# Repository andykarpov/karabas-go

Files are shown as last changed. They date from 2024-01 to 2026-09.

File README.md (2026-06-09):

# Karabas-Go

A Spartan-6 based devboard to emulate different retro-computers.



The hardware design and documentation are licensed under [Creative Commons Attribution-NonCommercial-ShareAlike 4.0 International](http://creativecommons.org/licenses/by-nc-sa/4.0/).

FPGA cores, the firmware and other software parts are licensed by their own licenses.

### What's on the board:

- A 25k LE's Spartan-6 FPGA
- RP2040 MCU
- 4x USB Ports
- 2x 2MB 10ns SRAM chips
- 32MB SDRAM chip
- VGA 8:8:8 output
- On-board FT812 video processor
- 16-bit audio DAC
- SAM2695 midi synth
- 2x Sega/Atari compatible DB9 joystick ports
- CF card
- 2x microSD cards
- Tape In/Out interface
- FDD port
- Buzzer
- DS3221 RTC
- 1kB EEPROM
- ESP8266 Wi-Fi module

### PCB 

The latest PCB revision number is Rev.B4.
PCB Changelog: https://github.com/andykarpov/karabas-go/blob/master/PCB_CHANGELOG.md

Warning: Rev.B4 could be a bit incompatible with the 3D enclosure models due to microSD cards shifted a bit forward.

### FPGA Core Sources

- Boot Menu Core: https://github.com/andykarpov/karabas-go-core-menu
- Test Core: https://github.com/andykarpov/karabas-go-core-test
- TS-Conf Core: https://github.com/andykarpov/karabas-go-core-tsconf
- ZX Spectrum Next Core: https://github.com/andykarpov/karabas-go-core-next
- Karabas Pro Core: https://github.com/andykarpov/karabas-go-core-profi
- PCXT Core: https://github.com/andykarpov/karabas-go-core-pcxt
- NES Core: https://github.com/andykarpov/karabas-go-core-nes
- Radio RK86 Core: https://github.com/andykarpov/karabas-go-core-rk86
- Alf Core: https://github.com/andykarpov/karabas-go-core-alf
- PDP-11/70: https://github.com/tsybulin/karabas-go-core-pdp2026

### The Firmware Sources

- https://github.com/andykarpov/karabas-go-firmware

### Dev Tools

- https://github.com/andykarpov/karabas-go-tools

### PCB

- https://github.com/andykarpov/karabas-go-pcb

### Pre-production renders:

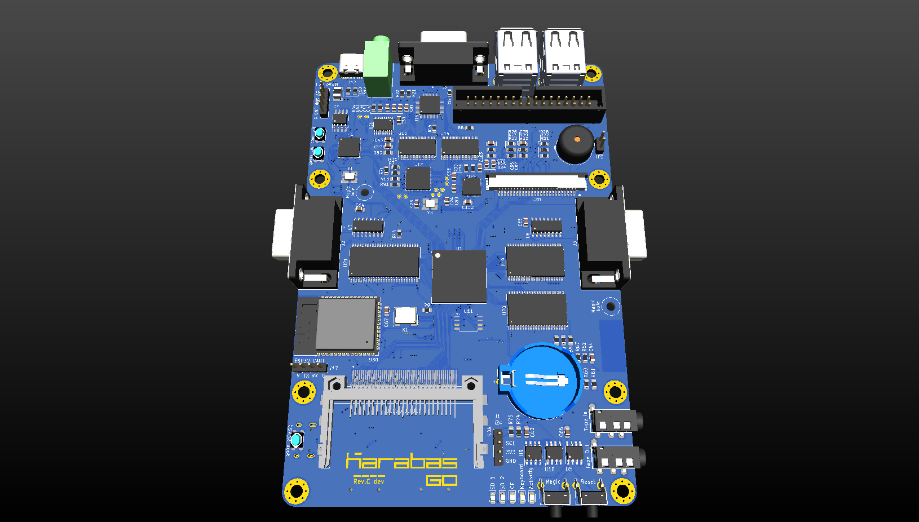
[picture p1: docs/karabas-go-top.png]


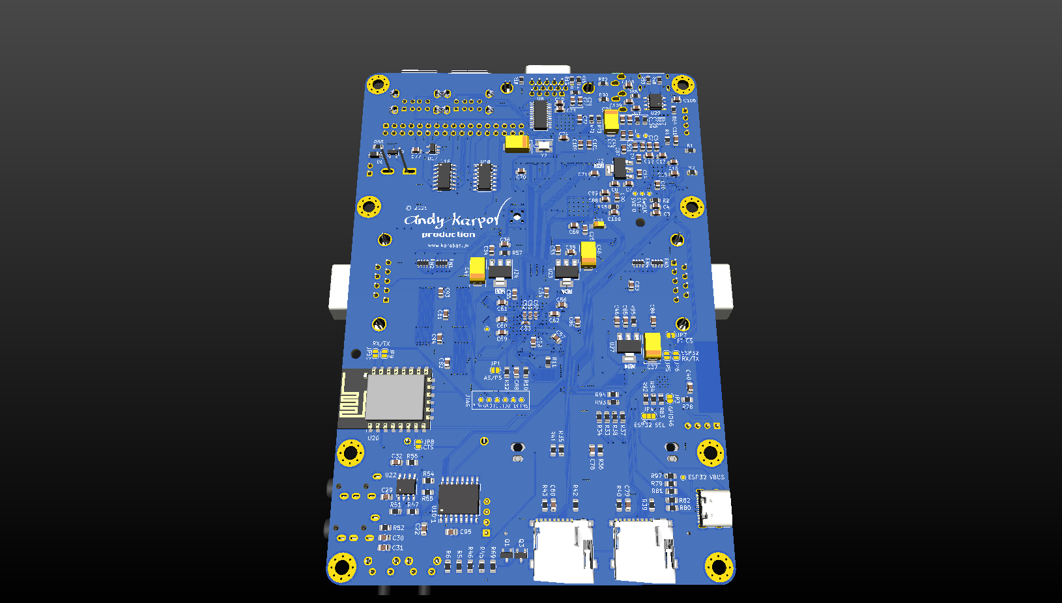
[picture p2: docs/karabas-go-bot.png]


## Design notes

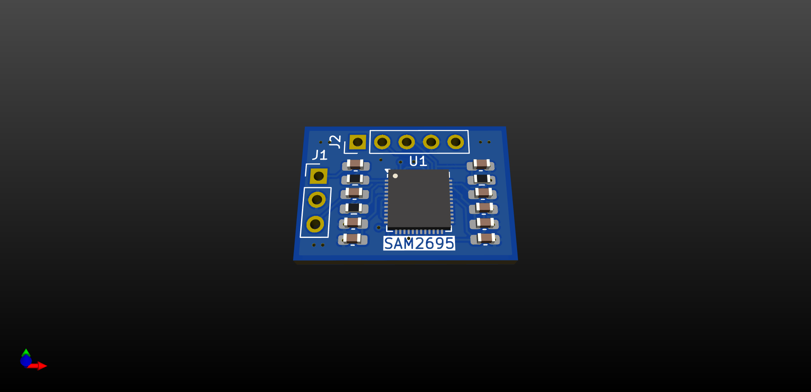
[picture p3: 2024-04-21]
docs/karabas-go-dream-addon.png

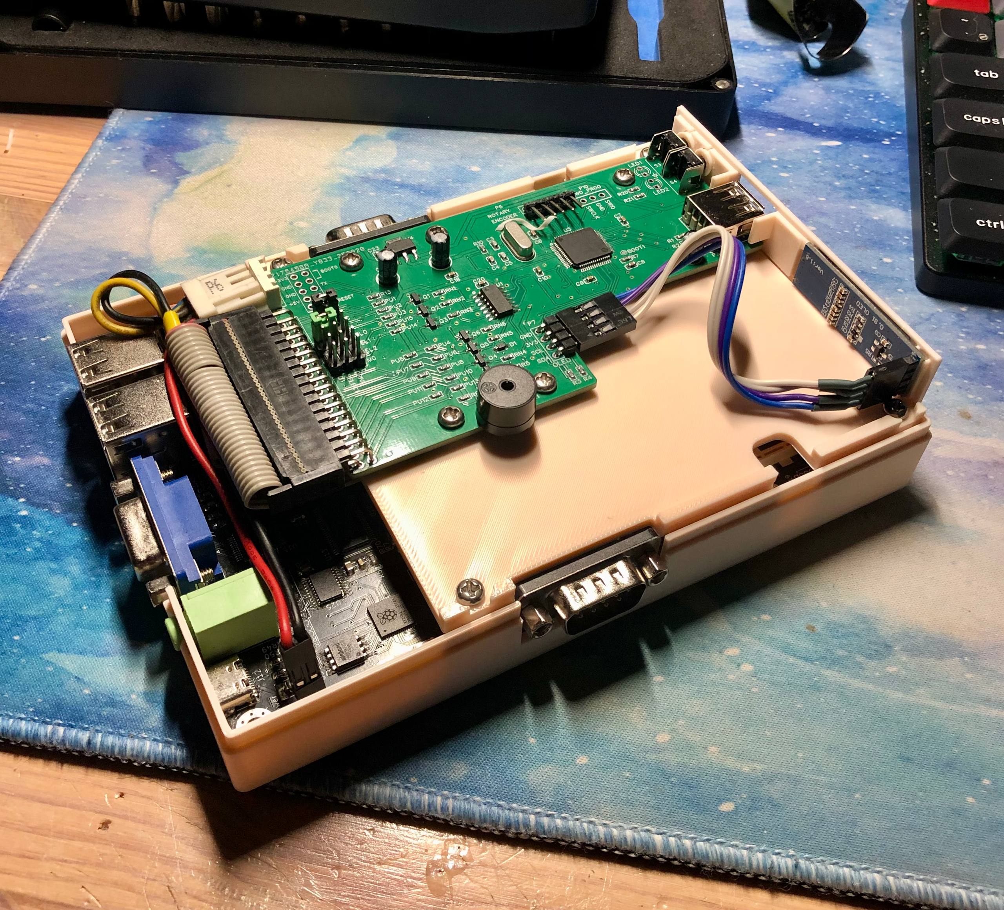
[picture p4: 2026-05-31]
case/gotek_b4/gotek_b4_photo2.jpg

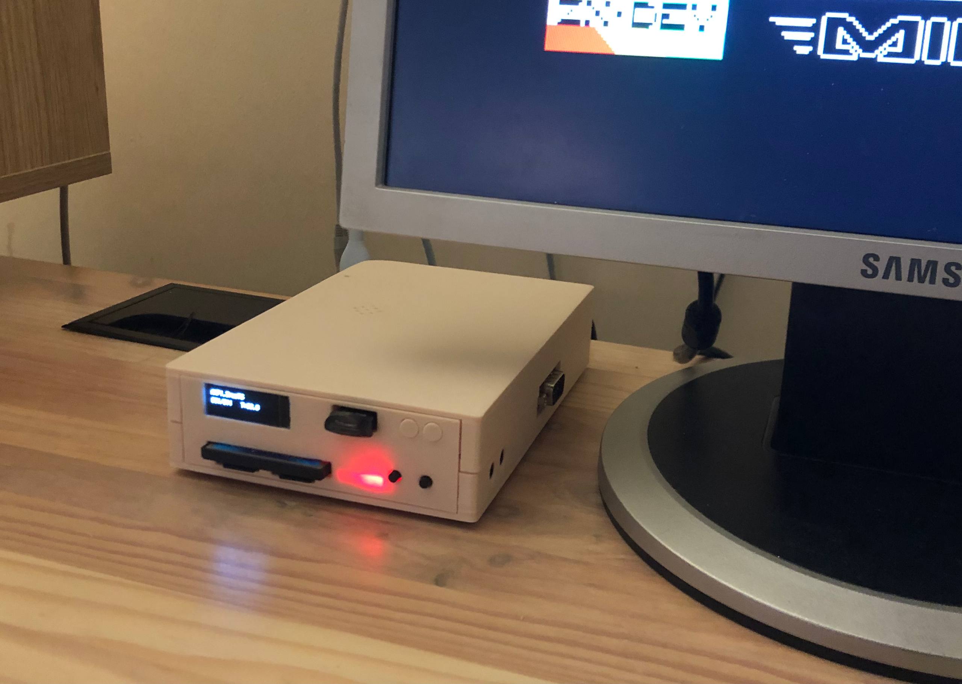
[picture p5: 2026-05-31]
case/gotek_b4/gotek_b4_photo1.jpg

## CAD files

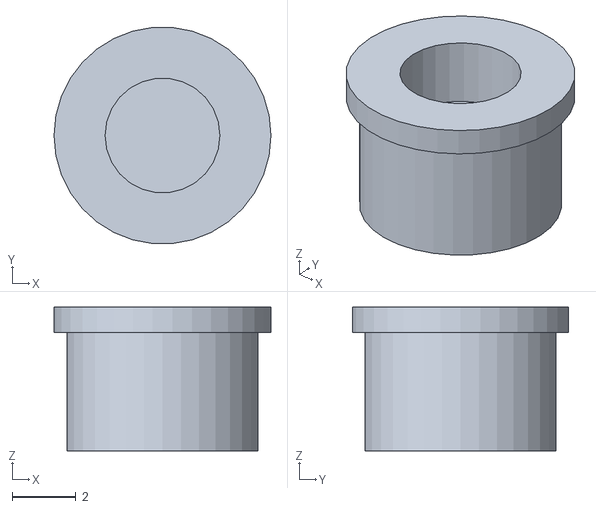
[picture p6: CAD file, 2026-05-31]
case/gotek_b4/gotek-button-x2.stl
6.80 x 6.77 x 4.50

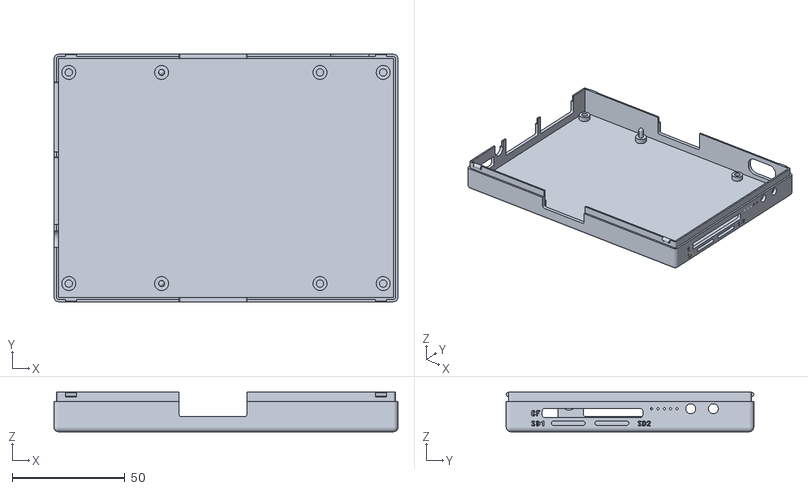
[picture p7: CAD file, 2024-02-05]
case/slim_v1/karabas-go-case-bot.stl
152.3 x 109.6 x 17.5

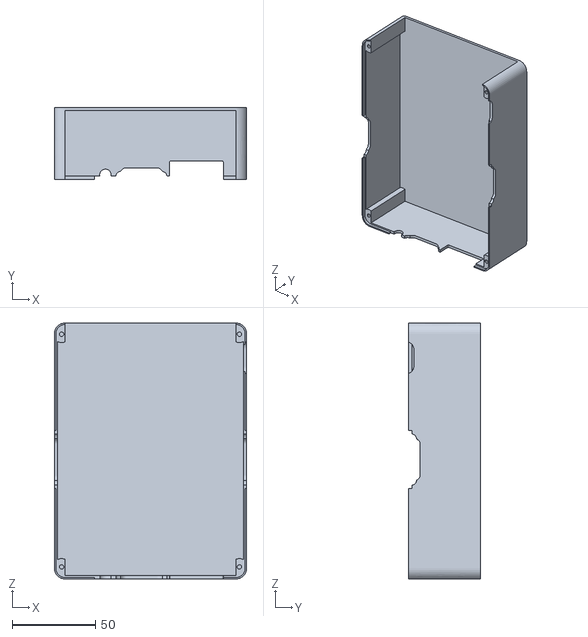
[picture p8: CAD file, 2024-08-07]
case/sserg_b4/Karabas_Go_wd_logo_-_case_top_v1.0. 20mm.stl
115.3 x 43.0 x 153.3

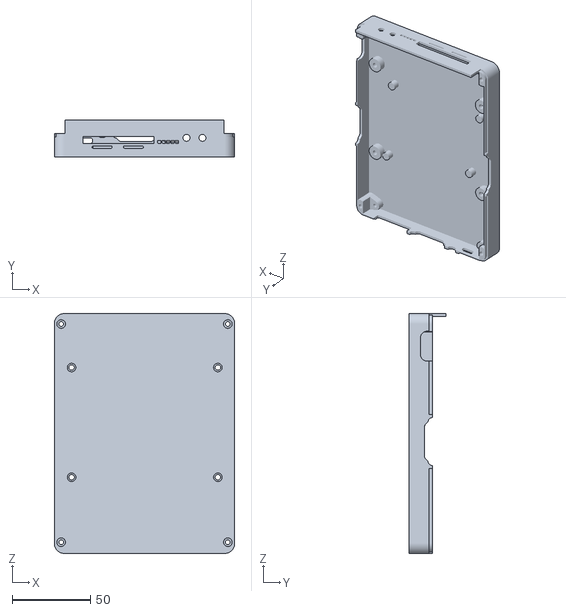
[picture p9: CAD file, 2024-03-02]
case/xdemox_with_fdd/with logo/big logo/Karabas_Go_wd_case_bottom_v1.2.stl
115.3 x 23.5 x 153.3

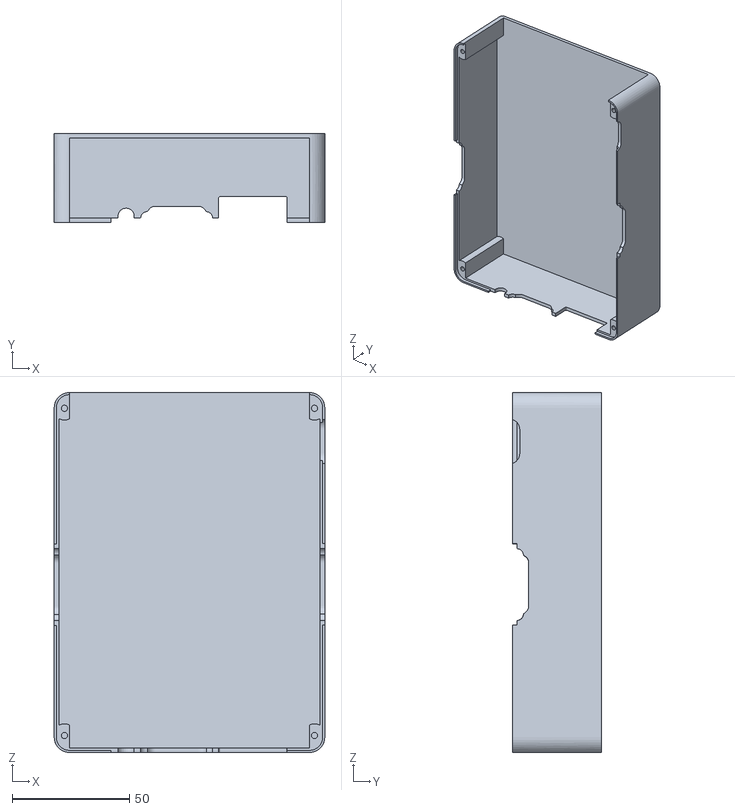
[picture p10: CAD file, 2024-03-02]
case/xdemox_with_fdd/with logo/small logo/Karabas_Go_wd_logo_I_case_top_v1.0.stl
115.3 x 38.0 x 153.3

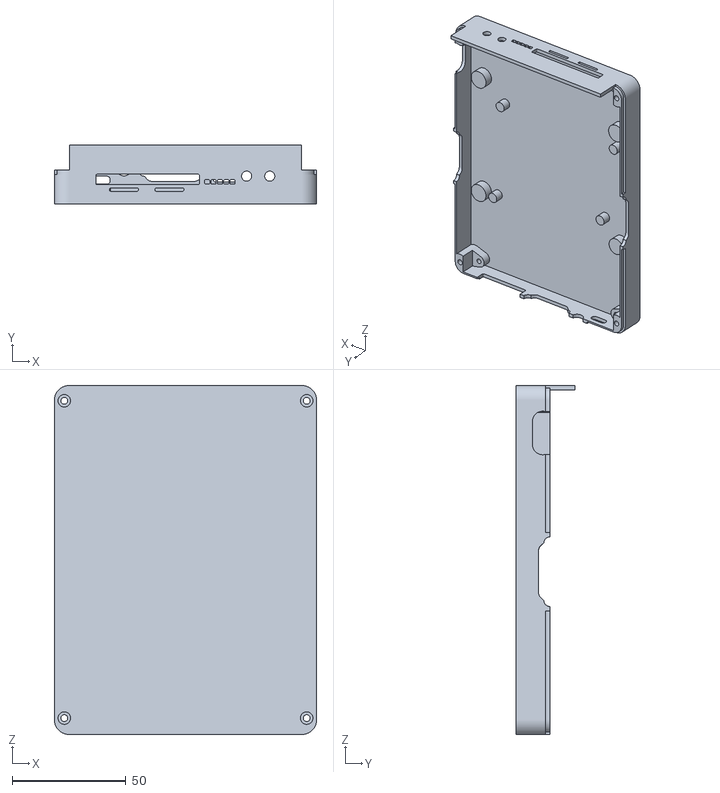
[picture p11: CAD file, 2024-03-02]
case/xdemox_without_fdd/with logo/big logo/Karabas_Go_wod_case_bottom_v1.2.stl
115.3 x 25.8 x 153.3

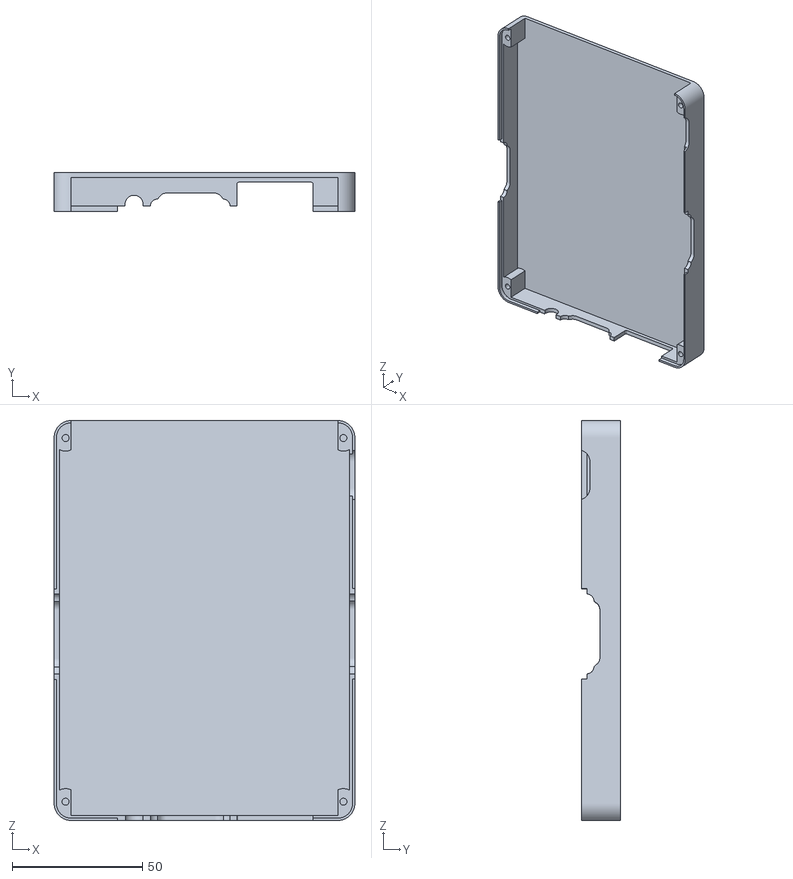
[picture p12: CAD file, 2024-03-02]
case/xdemox_without_fdd/without logo/Karabas_Go_wod_case_top_v1.0.stl
115.3 x 14.8 x 153.3

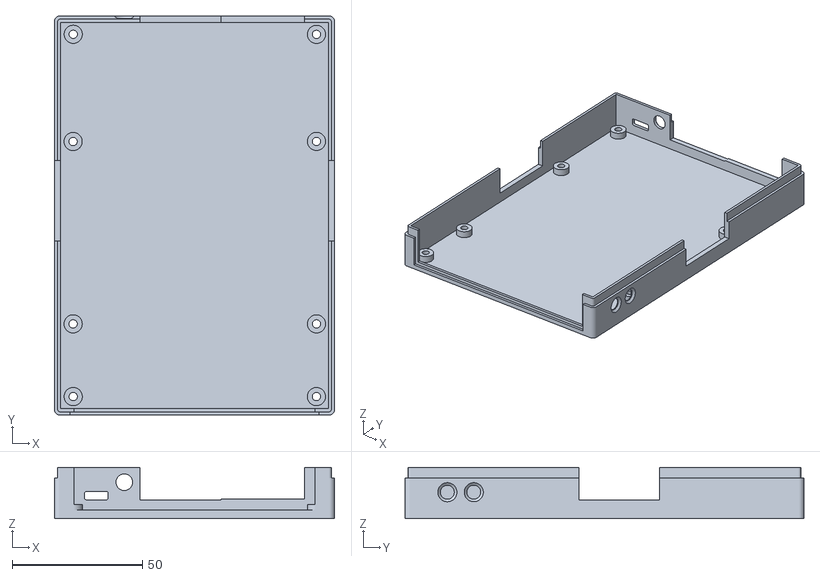
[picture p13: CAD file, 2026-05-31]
case/gotek_b4/bottom.stl
107.6 x 153.3 x 19.7

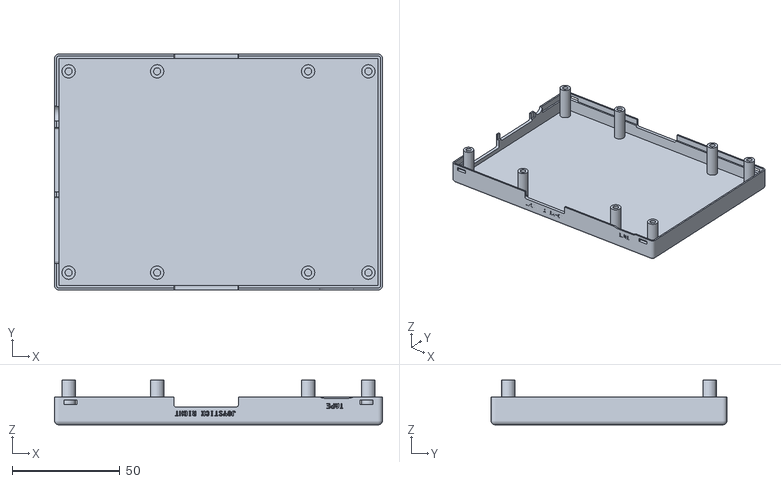
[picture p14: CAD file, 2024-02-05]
case/slim_v1/karabas-go-case-top.stl
152.3 x 109.6 x 20.7

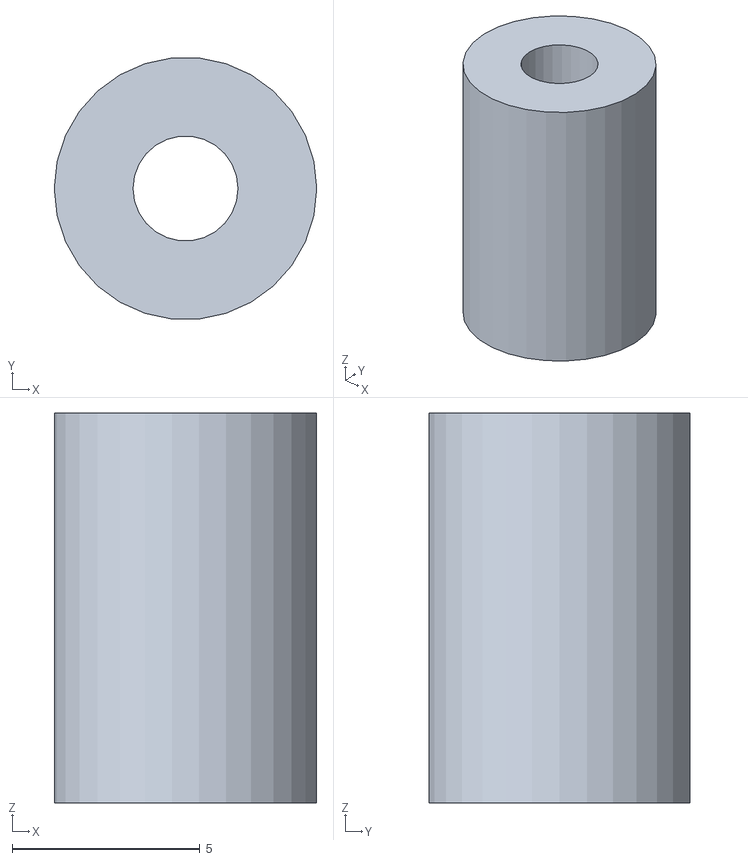
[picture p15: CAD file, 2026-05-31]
case/gotek_b4/gotek-pillar-x4.stl
7.00 x 6.96 x 10.4

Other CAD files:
case/xdemox_with_fdd/without logo/Karabas_Go_wd_case_top_v1.0.stl
case/xdemox_with_fdd/with logo/big logo/Karabas_Go_wd_round led_case_bottom_v1.2.stl
case/xdemox_with_fdd/with logo/small logo/Karabas_Go_wd_round led_case_bottom_v1.2.stl
case/xdemox_with_fdd/without logo/Karabas_Go_wd_round led_case_bottom_v1.2.stl
case/xdemox_without_fdd/with logo/big logo/Karabas_Go_wod_round led_case_bottom_v1.2.stl
case/xdemox_without_fdd/with logo/small logo/Karabas_Go_wod_logo_I_case_top_v1.0.stl
case/xdemox_without_fdd/without logo/Karabas_Go_wod_round led_case_bottom_v1.2.stl
case/gotek_b4/front.stl
case/gotek_b4/gotek.stl
case/gotek_b4/top.stl
case/xdemox_with_fdd/with logo/big logo/Karabas_Go_wd_logo_-_case_top_v1.0.stl
case/xdemox_without_fdd/with logo/big logo/Karabas_Go_wod_logo_-_case_top_v1.0.stl
case/xdemox_without_fdd/with logo/small logo/Karabas_Go_wod_round led_case_bottom_v1.2.stl

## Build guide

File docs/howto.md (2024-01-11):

# Karabas Go How-to

How to prepare the newly created devboard to run:

1. Prepare an SD card #1 with cores (*.kg1) in the root of SD card. The SD card could be FAT16, FAT32 or EXFAT formatted.

2. Upload the RP2040 firmware:

- Press and hold the "RP Boot" button
- Press then release the "RP Reset" button
- Release the "RP Boot" button
- Put the firmware.uf2 into a mounted drive
- Wait a bit until it reboots
- Done, the boot.kg1 core should starts

3. Profit

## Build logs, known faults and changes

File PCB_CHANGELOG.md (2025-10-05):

## Rev.C dev

- A development edition with ESP32 on board
- Cleanup, removed unused stuff
- Added ESP32-S3 module with connection to the FT QSPI and FPGA as I2S slave
-- ESP32 I2S bus connected to the unused conf flash pins CONF_IO0, CONF_IO2, CONF_IO3
-- ESP32_SPI_CS pin will use a ESP_BOOT or UART_CTS (this is an open question yet, a set of jumpers is exists to decide later)

Please do not use this version yet. The development is in progress...

## Rev.B4

- Moved CF card deeper
- Textual fixes on the bottom silkscreen
- Added THT RGB LEDs in parallel to the smd ones
- Replaced FPC connector for external SD cards to a pin headers 1.27mm pitch

## Rev.B3

- Cleanup
- Changed USB-A footprints
- Moved USB-A connectors 1mm deeper
- Moved USB-C and audio TRS connectors a bit out of the board

## Rev.B2

- Added FPC connectors for external SD cards
- Added FPC connector for slim FDD
- Added FT_PD ext reset, routed to MCU
- Added midi chip
- Added Op Amp to the sound output

## Rev.B1

- Added universal footprint for the ADV7125
- Fixed FE1.1s footprint
- Updated buzzer footprint
- Added alternate footprint for the DS3231M IC
- Added bus between MCU and FPGA
- Increased power rails width
- Swapped test points to a bottom side
- Replaced FPGA 0402 caps with 0603 caps

## Rev.B

- Bugfix revision
- Changed incorrect FT buffers direction
- Added missing power line to the RP2040
- Fixed some values

## Rev.A

- Initial Revision

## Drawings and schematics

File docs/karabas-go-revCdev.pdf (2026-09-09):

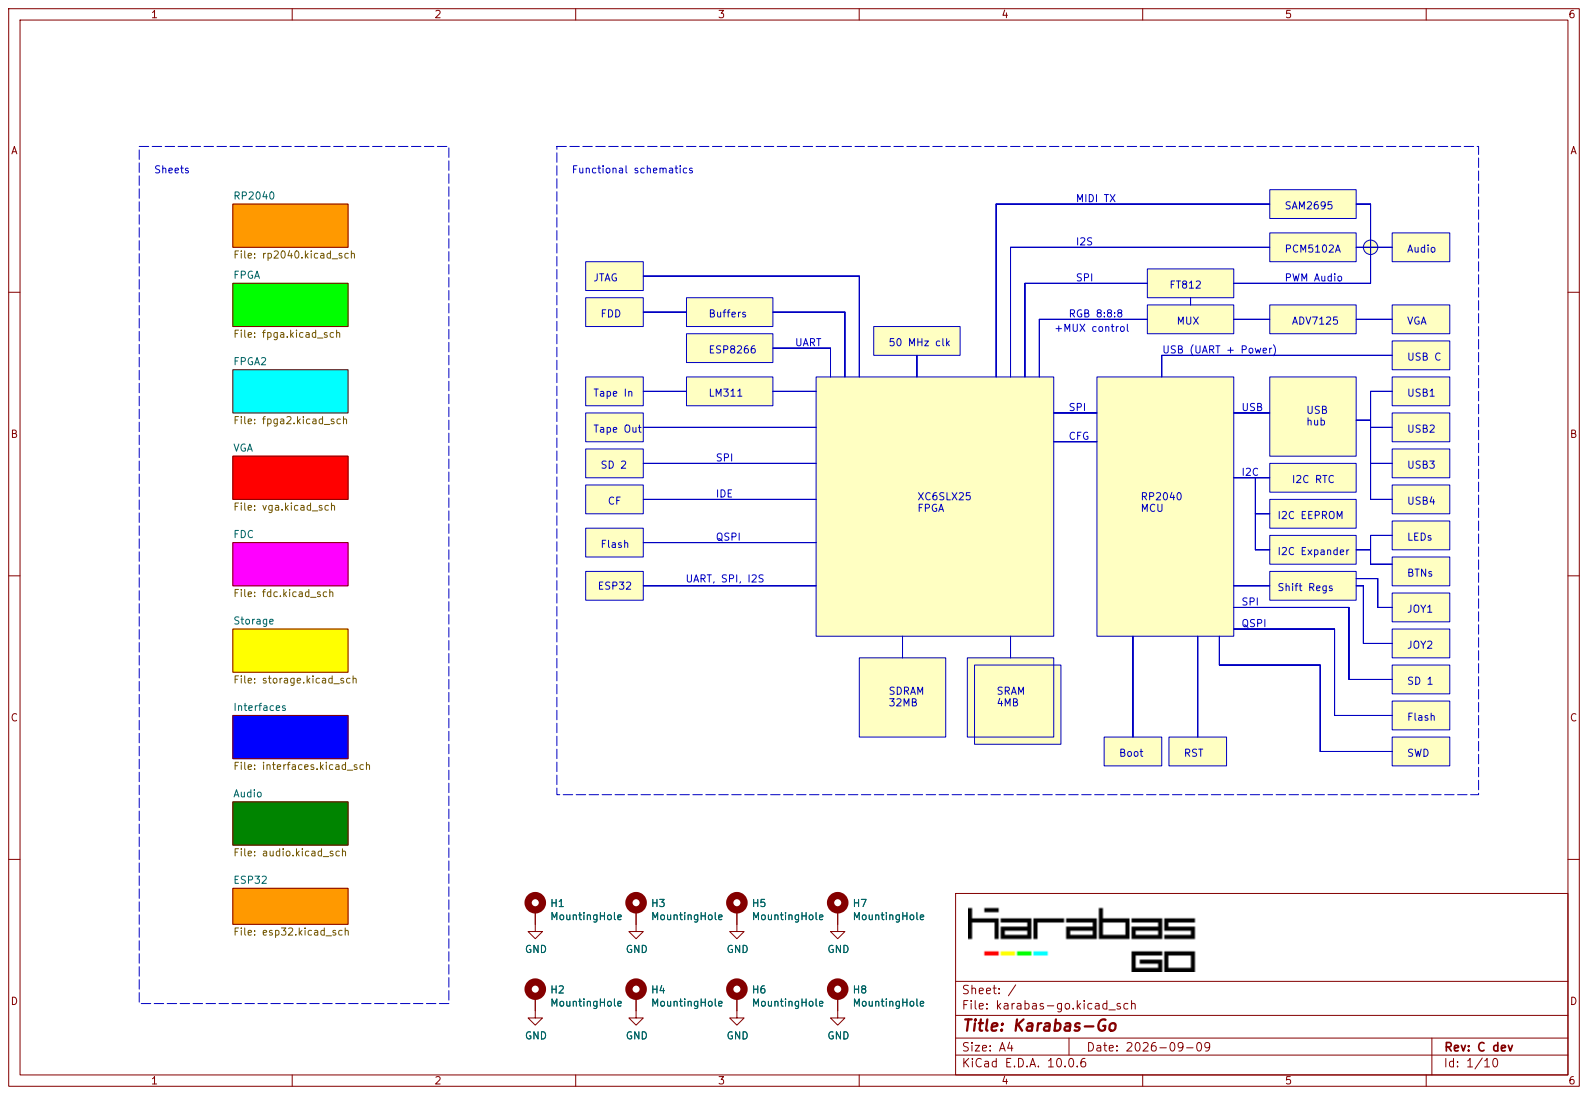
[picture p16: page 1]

Size: A4 | Rev: C dev
KiCad E.D.A. 10.0.6 | Id: 1/10

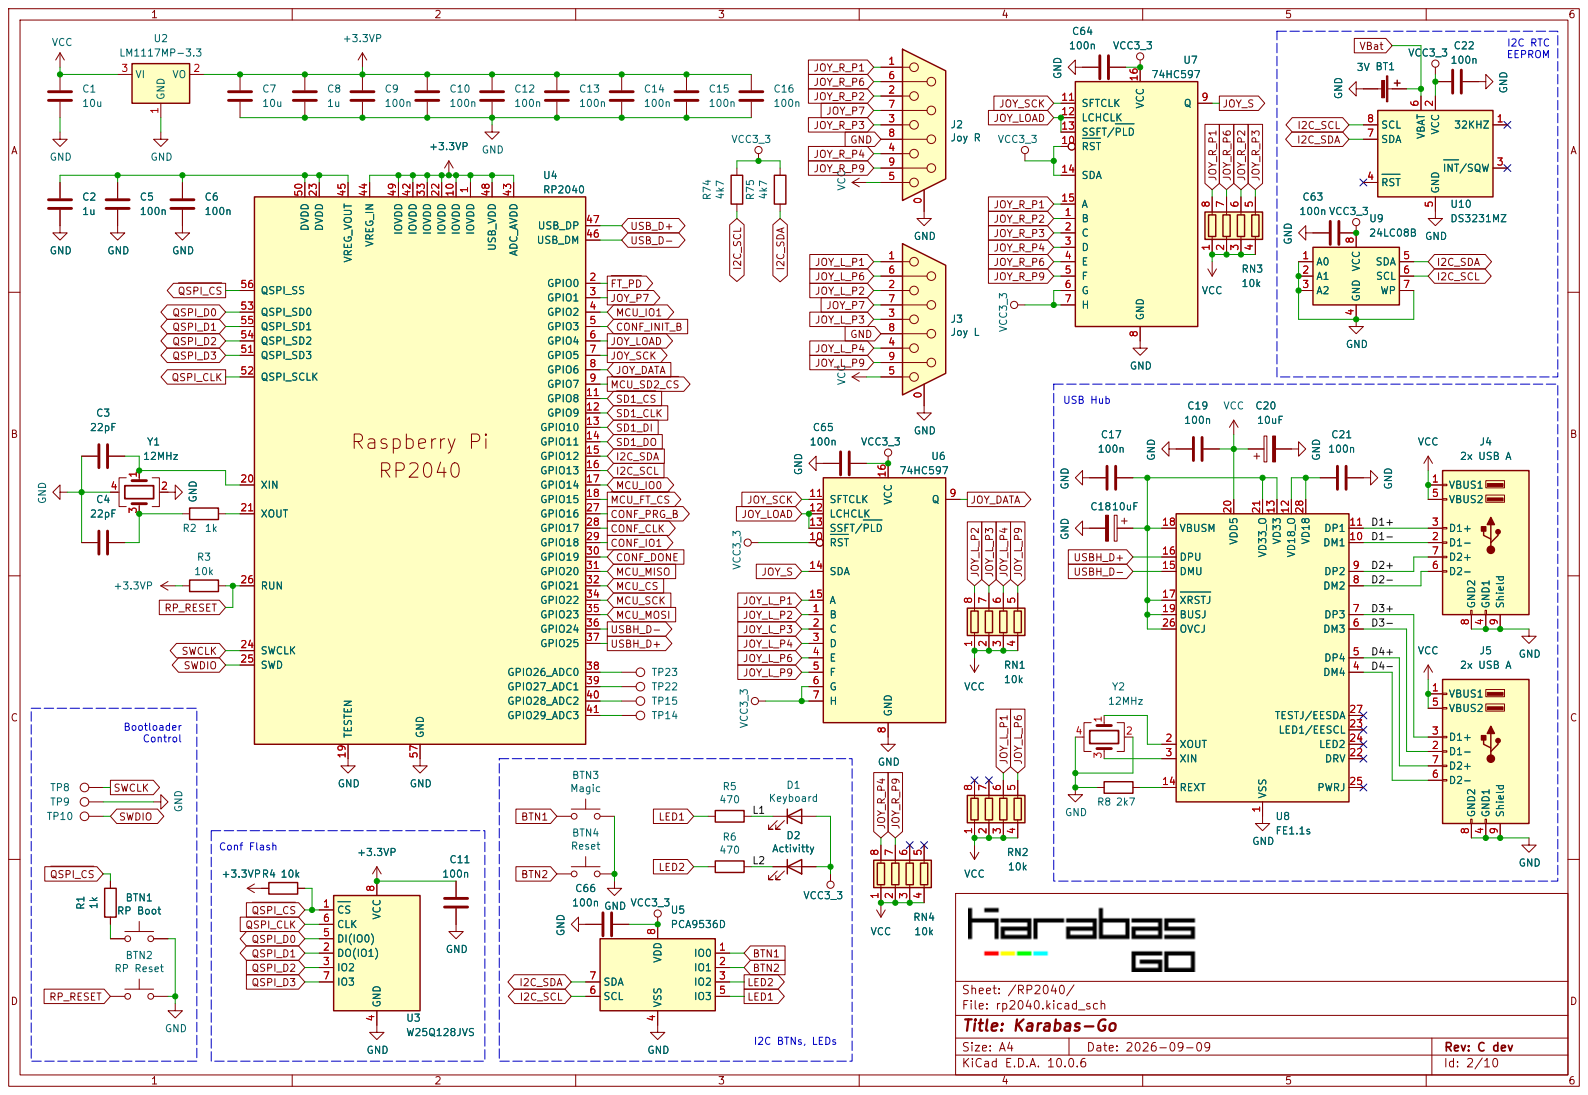
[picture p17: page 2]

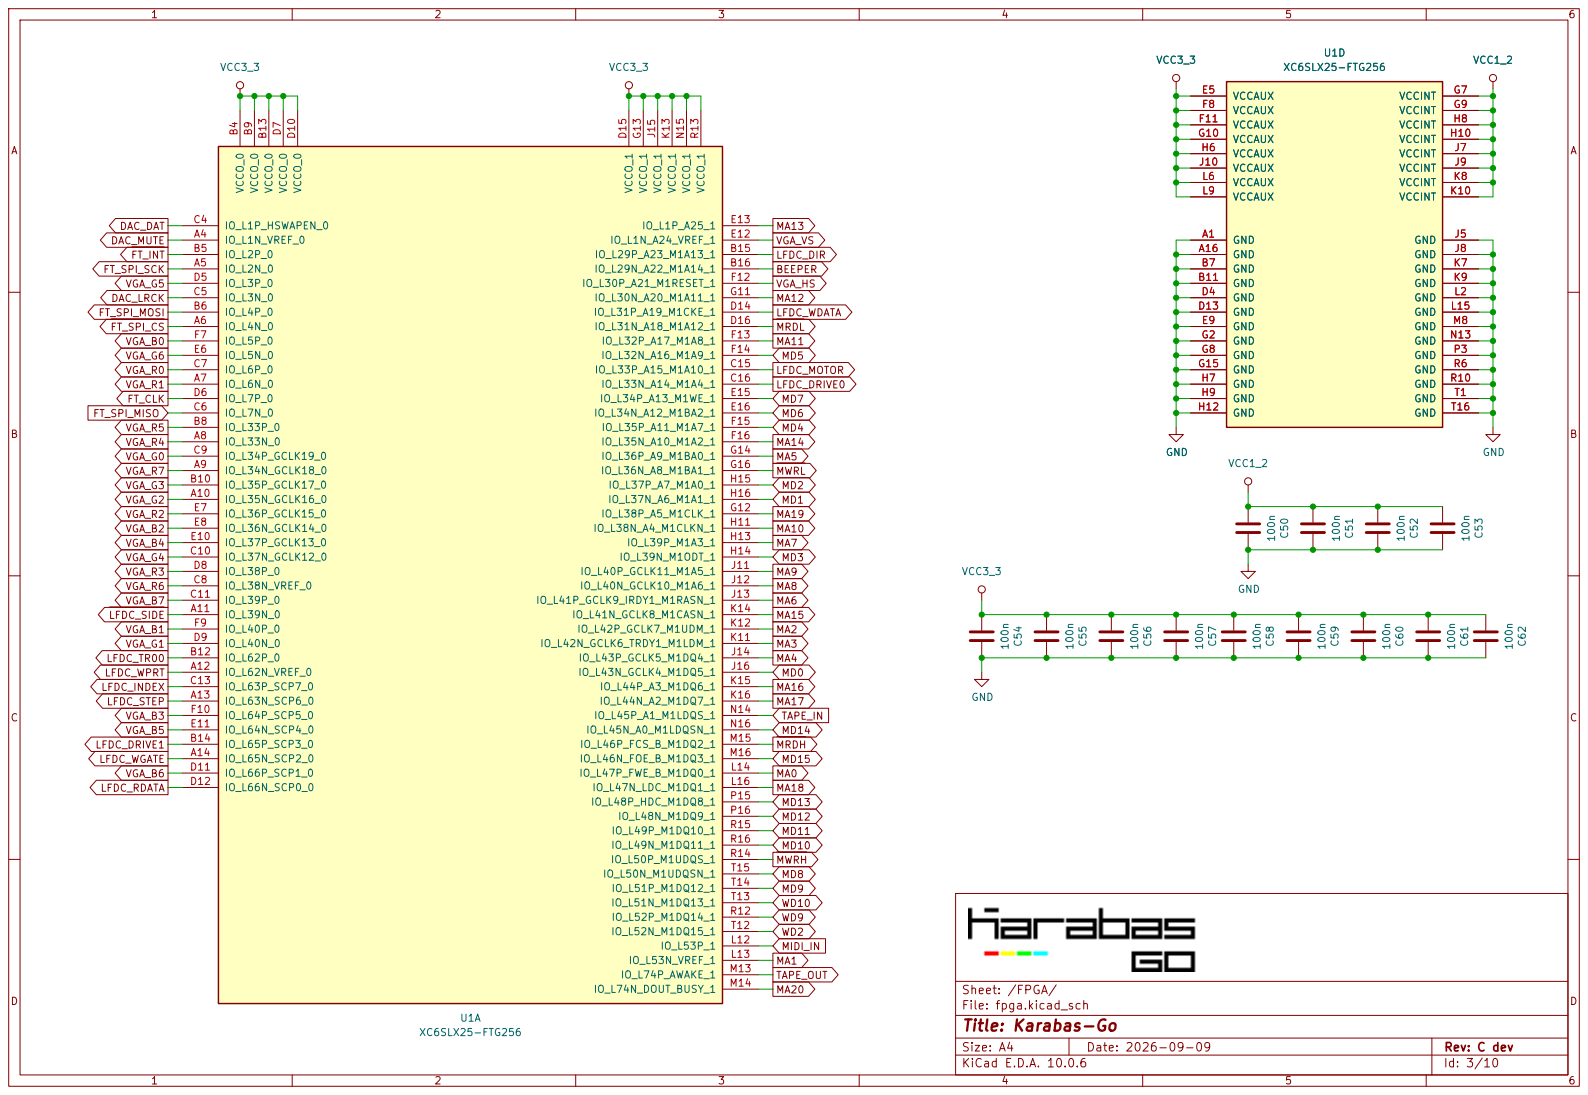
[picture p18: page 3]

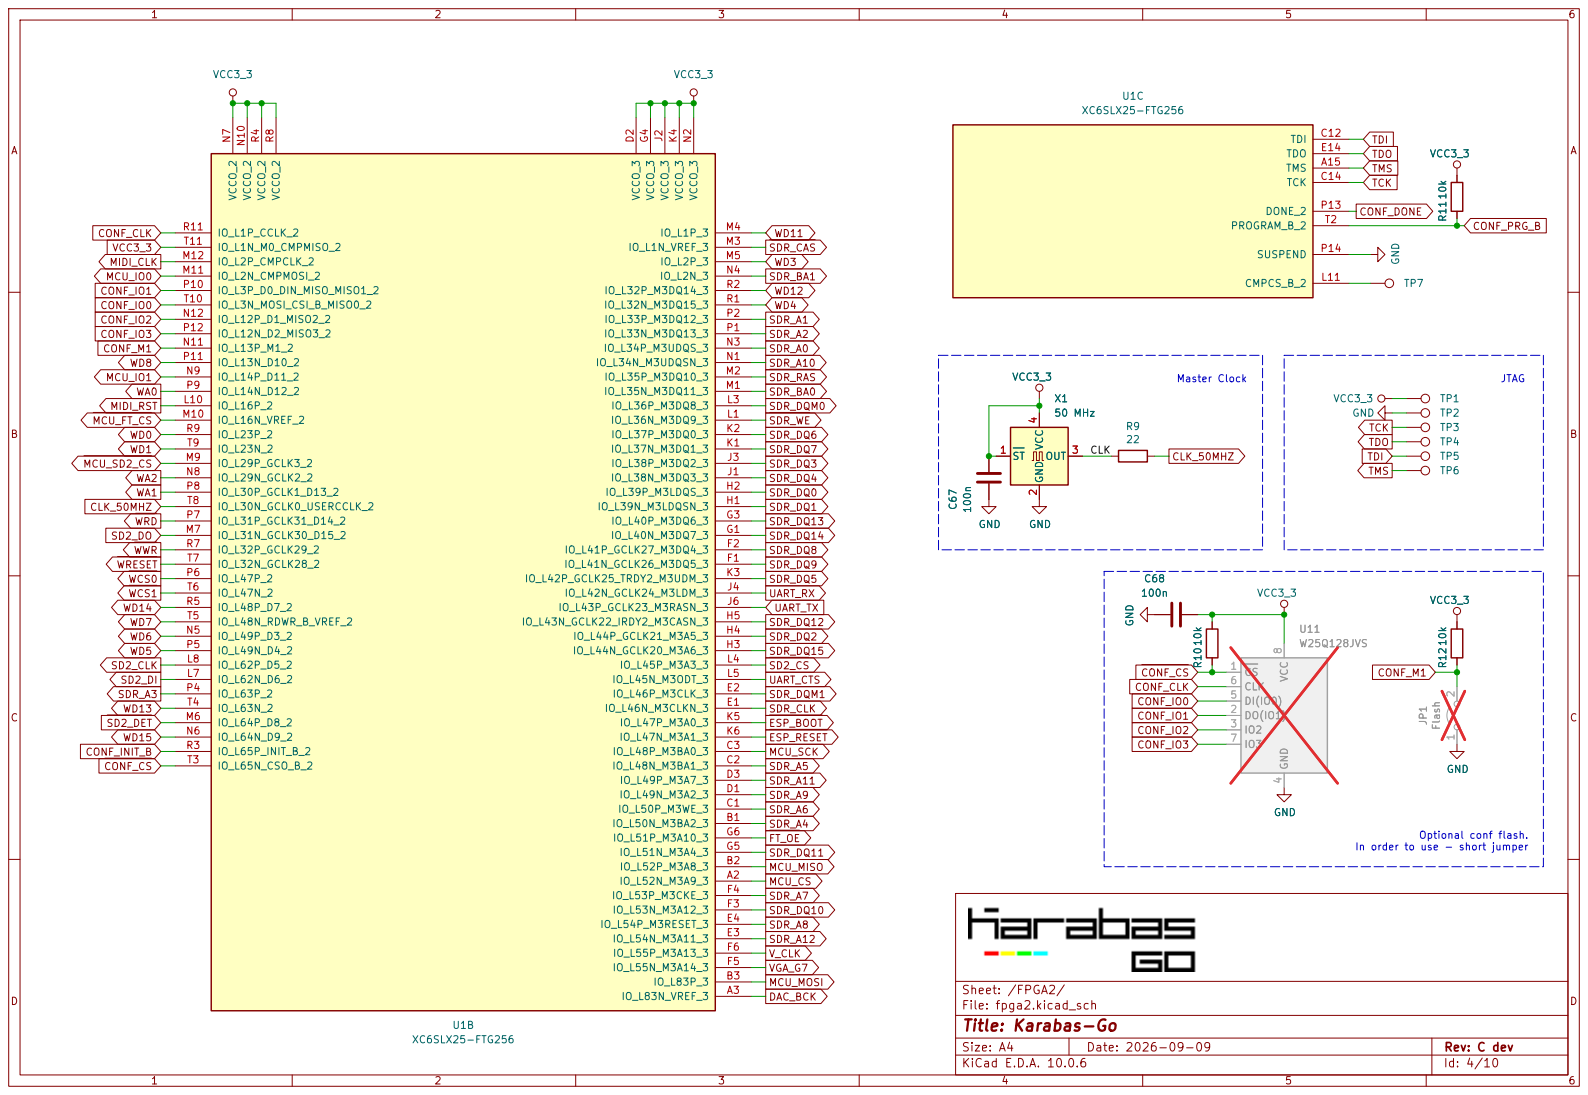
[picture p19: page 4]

In order to use - short jumper JP1 Flash 1 2 GND

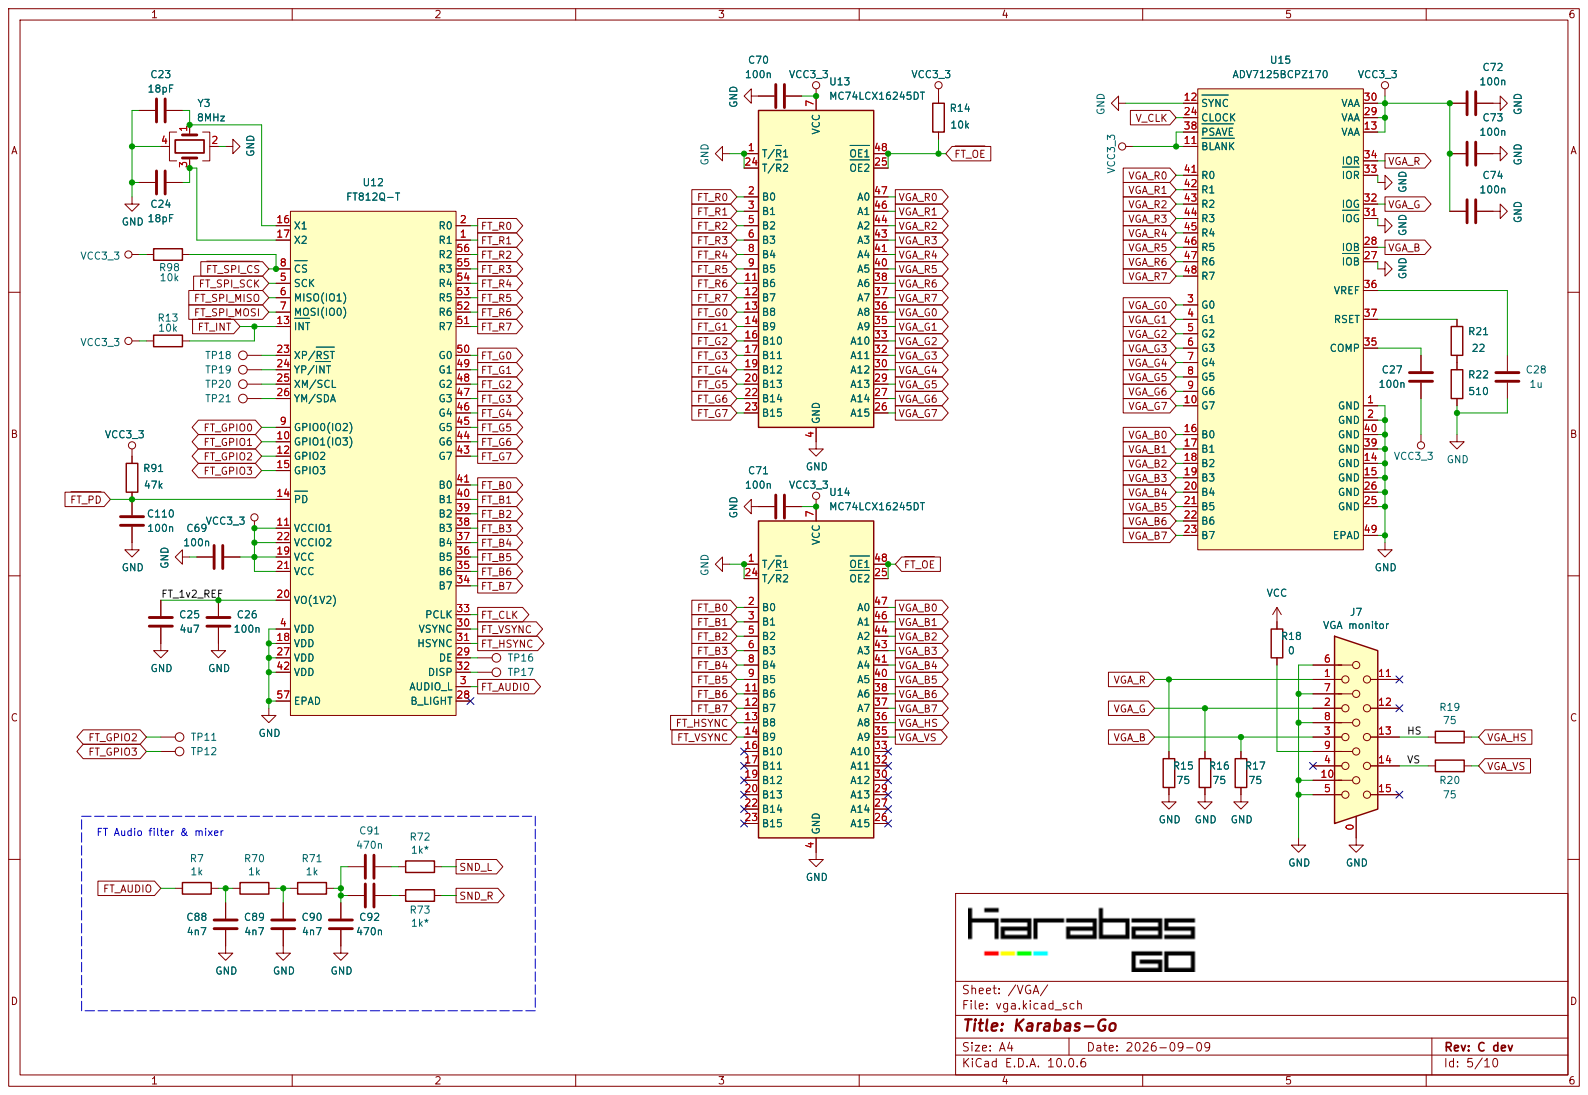
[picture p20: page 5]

XP/RST 23
YP/INT 24
XM/SCL 25
YM/SDA 26
VSYNC 30 HSYNC 31 DISP 32 PCLK 33 B7 34 B6 35 B5 36 B4 37 B3 38 B2 39 B1 40 B0 41

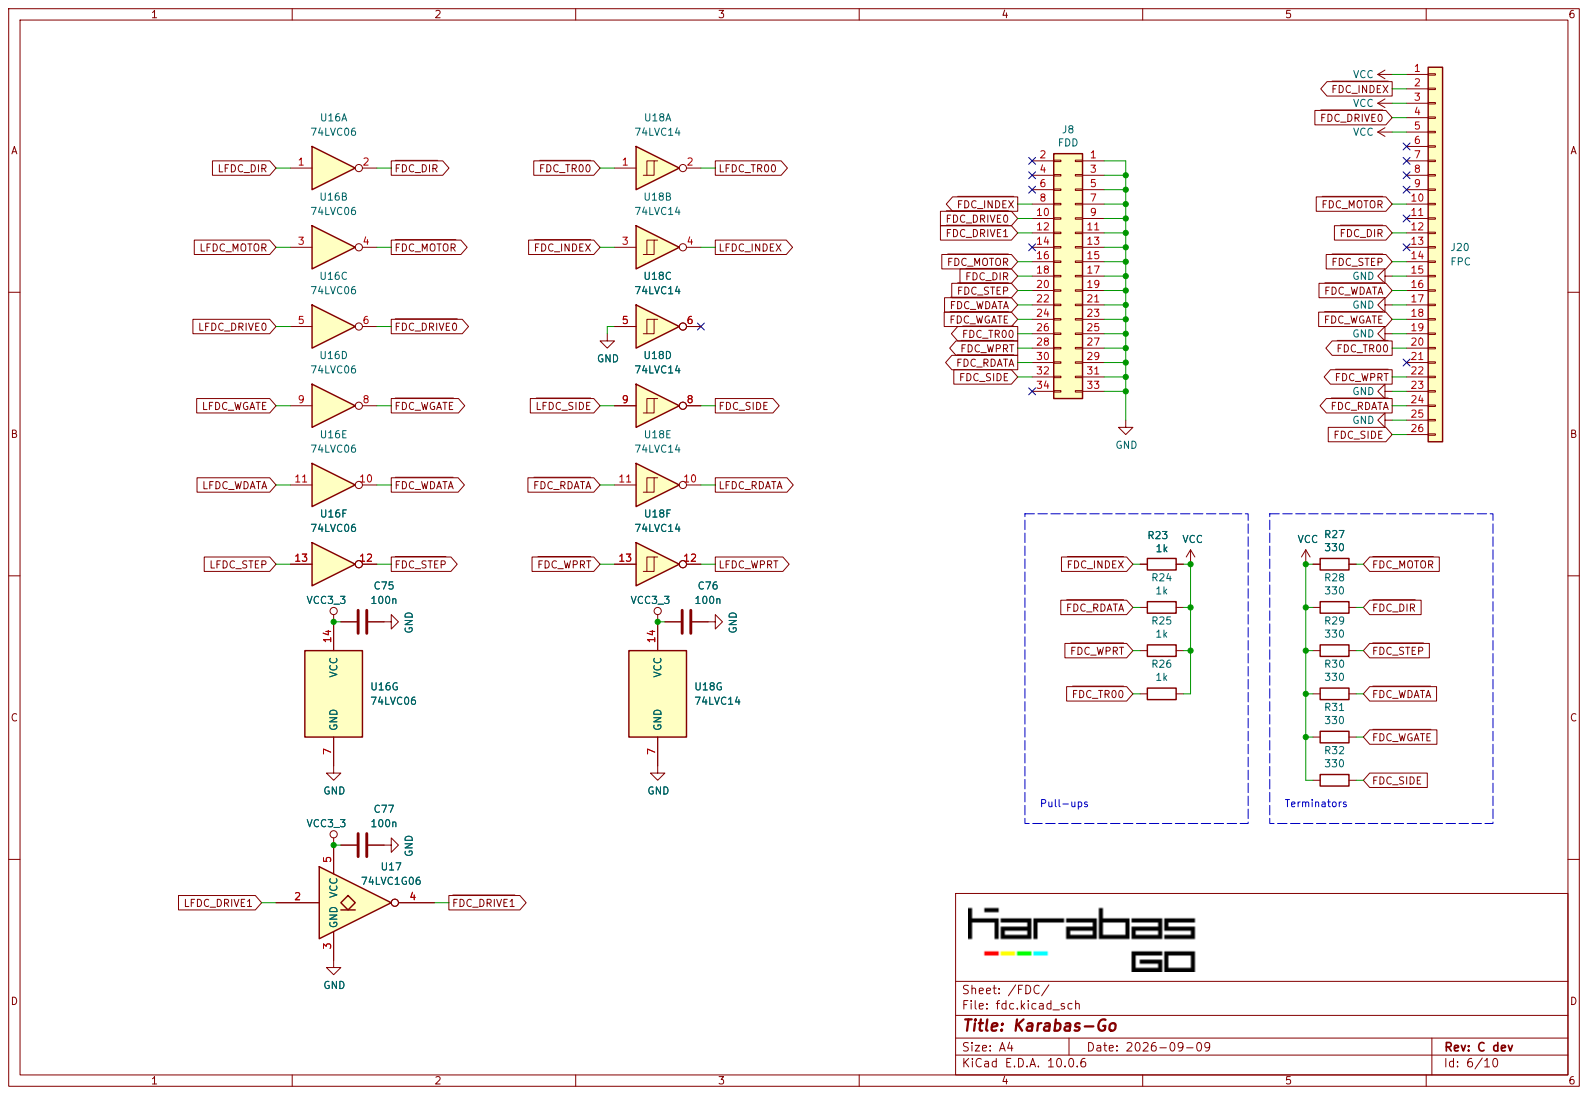
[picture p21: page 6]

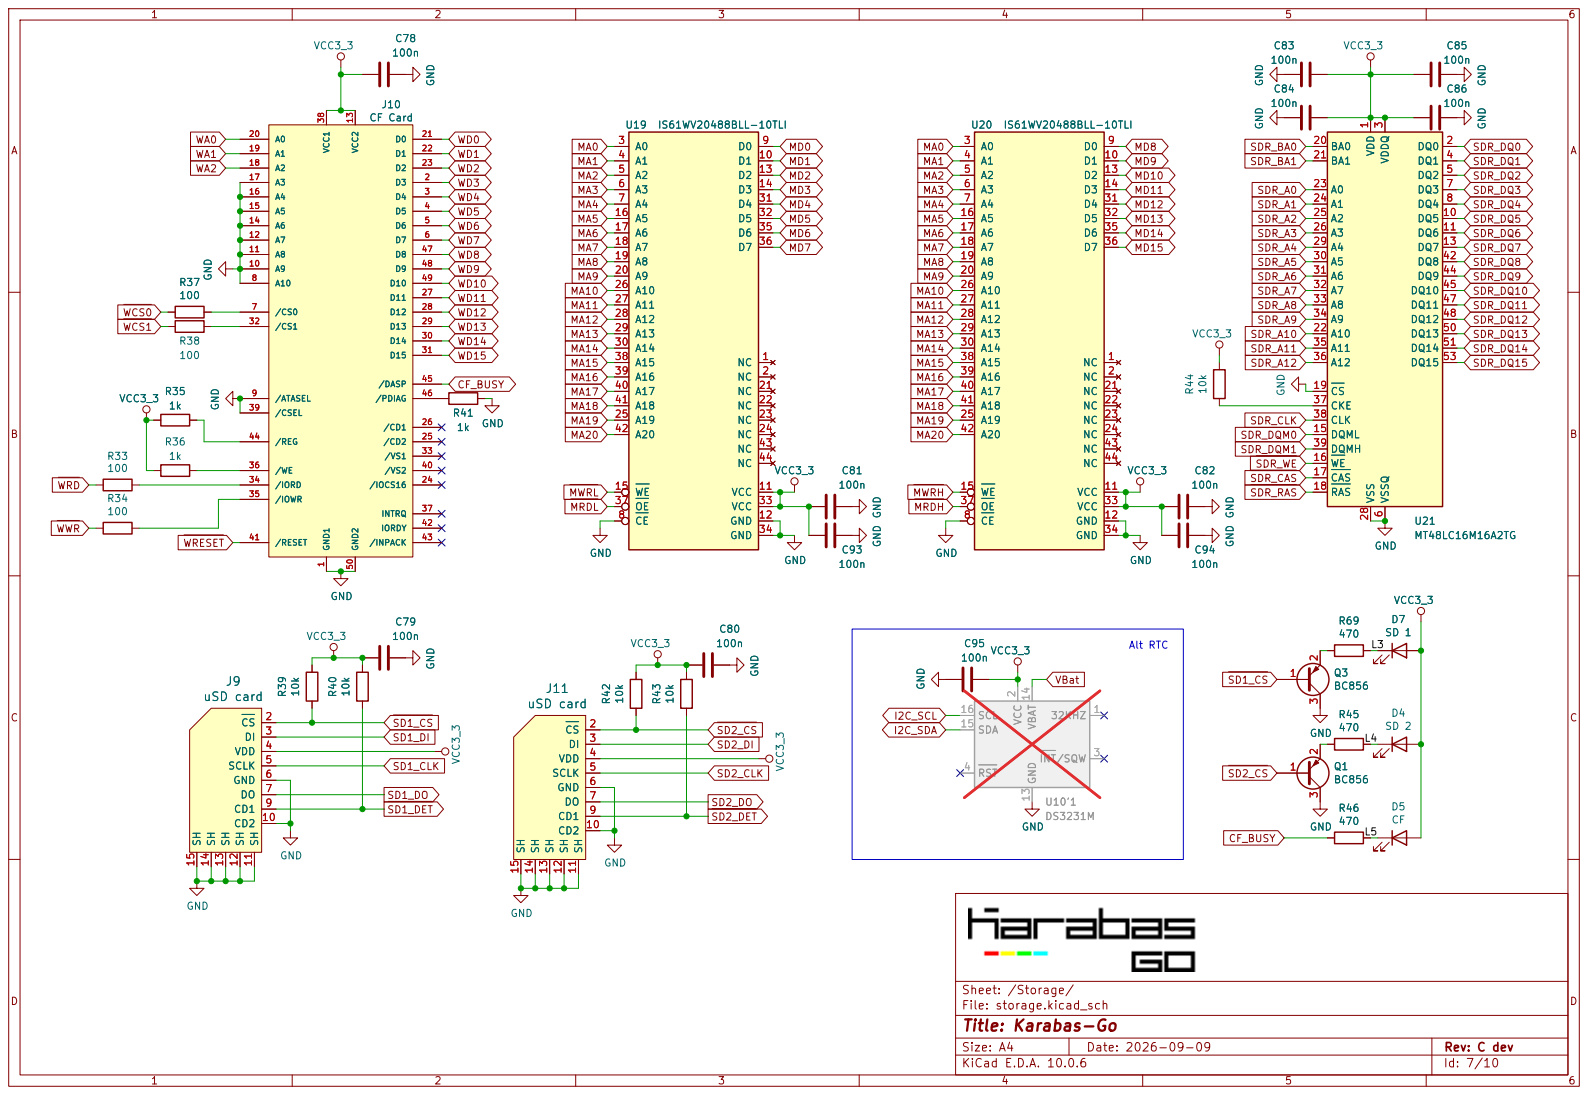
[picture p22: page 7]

uSD card GND GND

6 DQ3 7 DQ4 8 DQ5 10 DQ6 11 DQ7 13 DQML 15 WE 16 CAS 17 RAS 18 CS 19 BA0 20 BA1 21

SCLK 5 GND 6 DO 7 CD1 9 CD2 10 SH 11 SH 12 SH 13 SH 14 SH 15

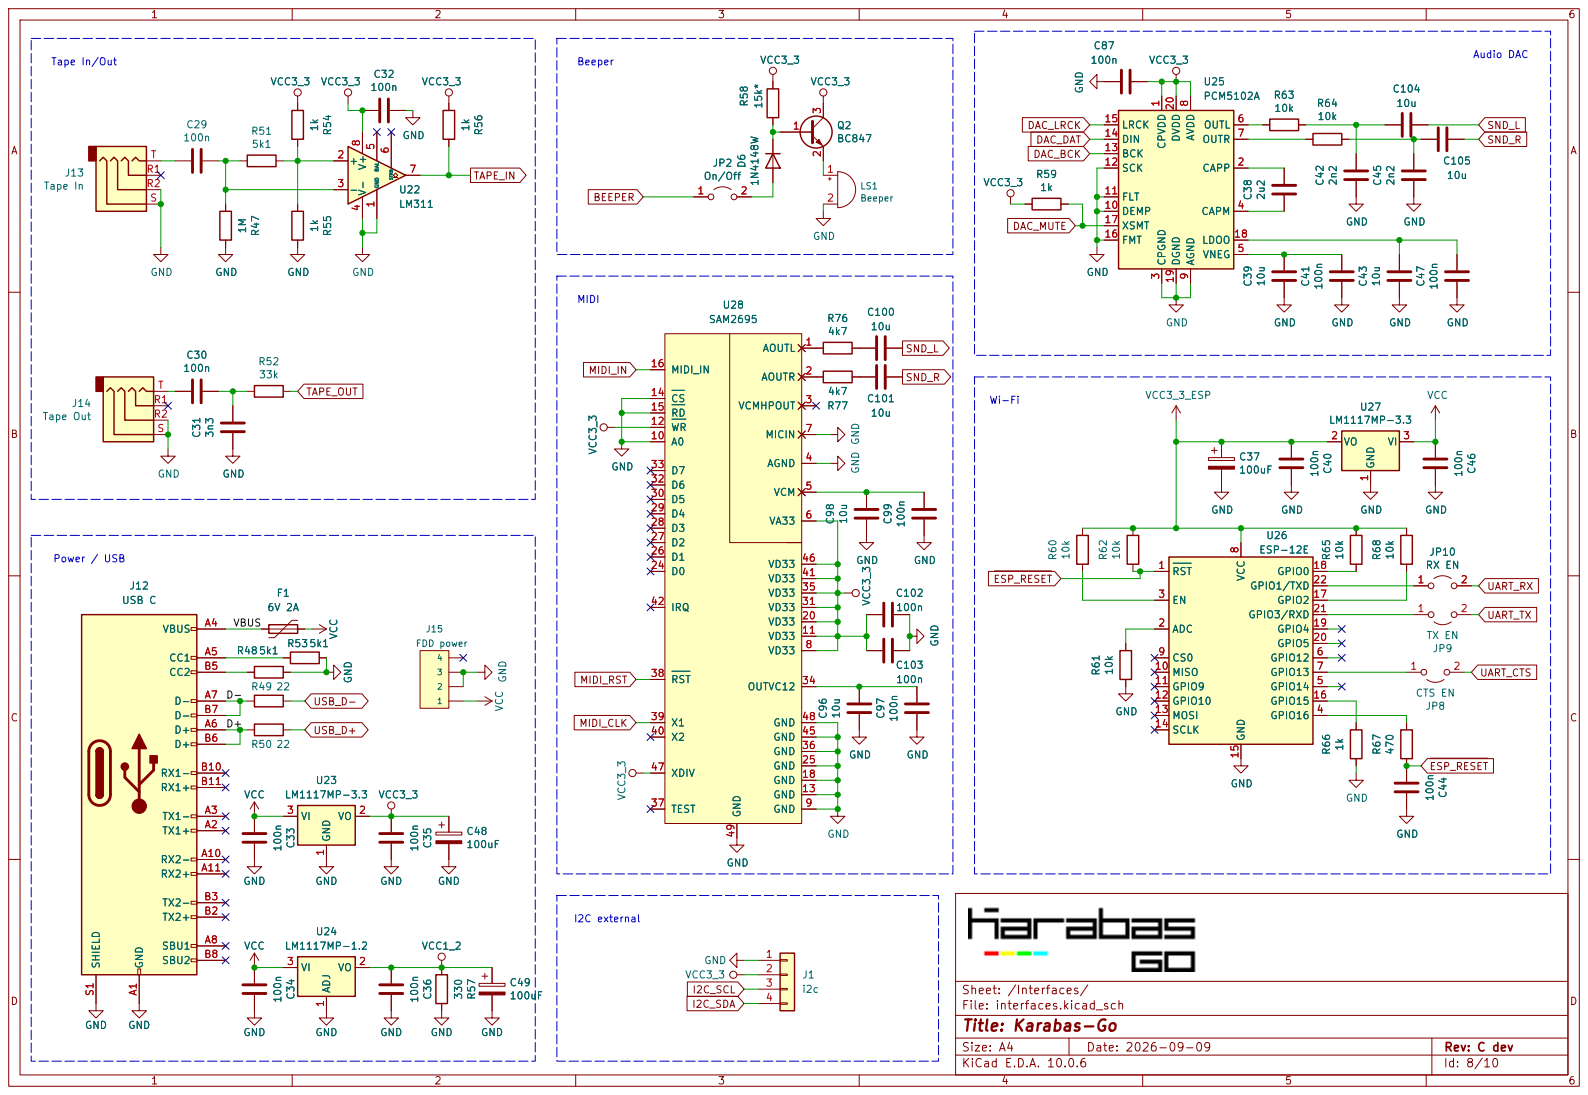
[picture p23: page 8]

SCK 12 BCK 13 DIN 14 LRCK 15

Wi-Fi Power / USB

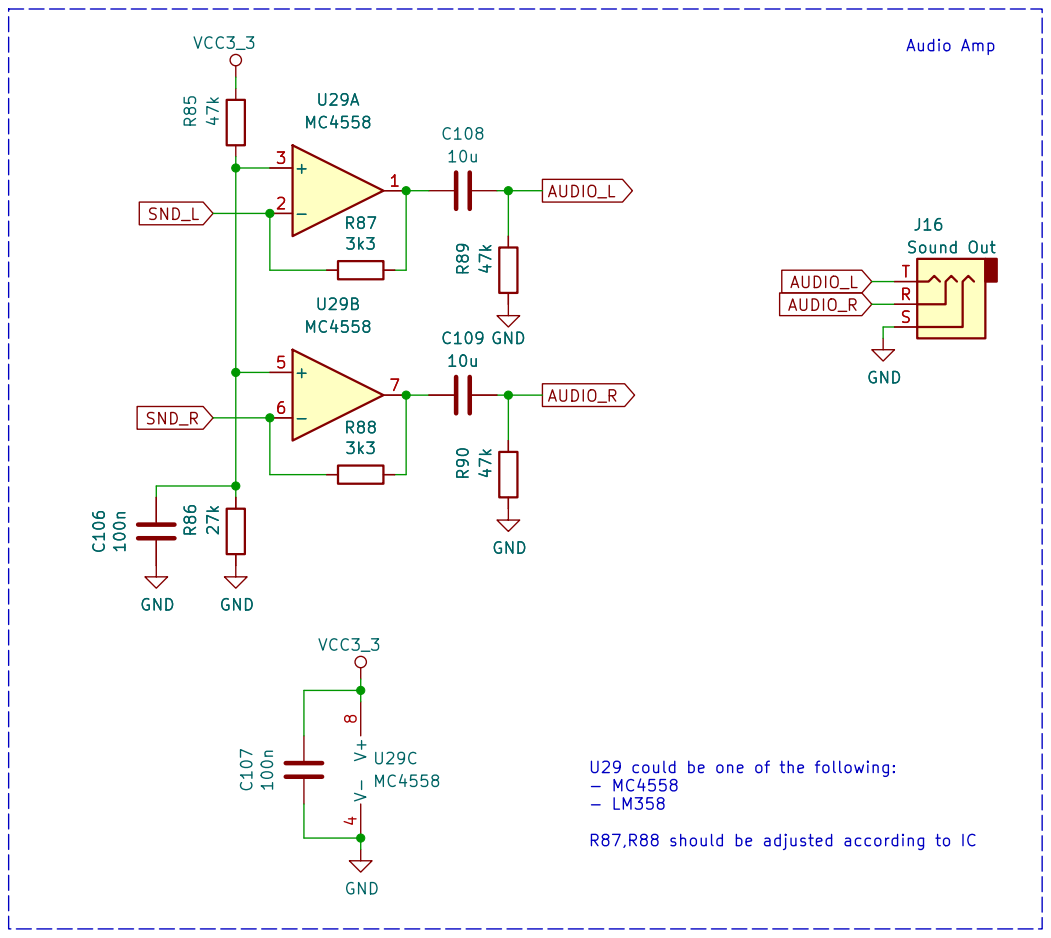
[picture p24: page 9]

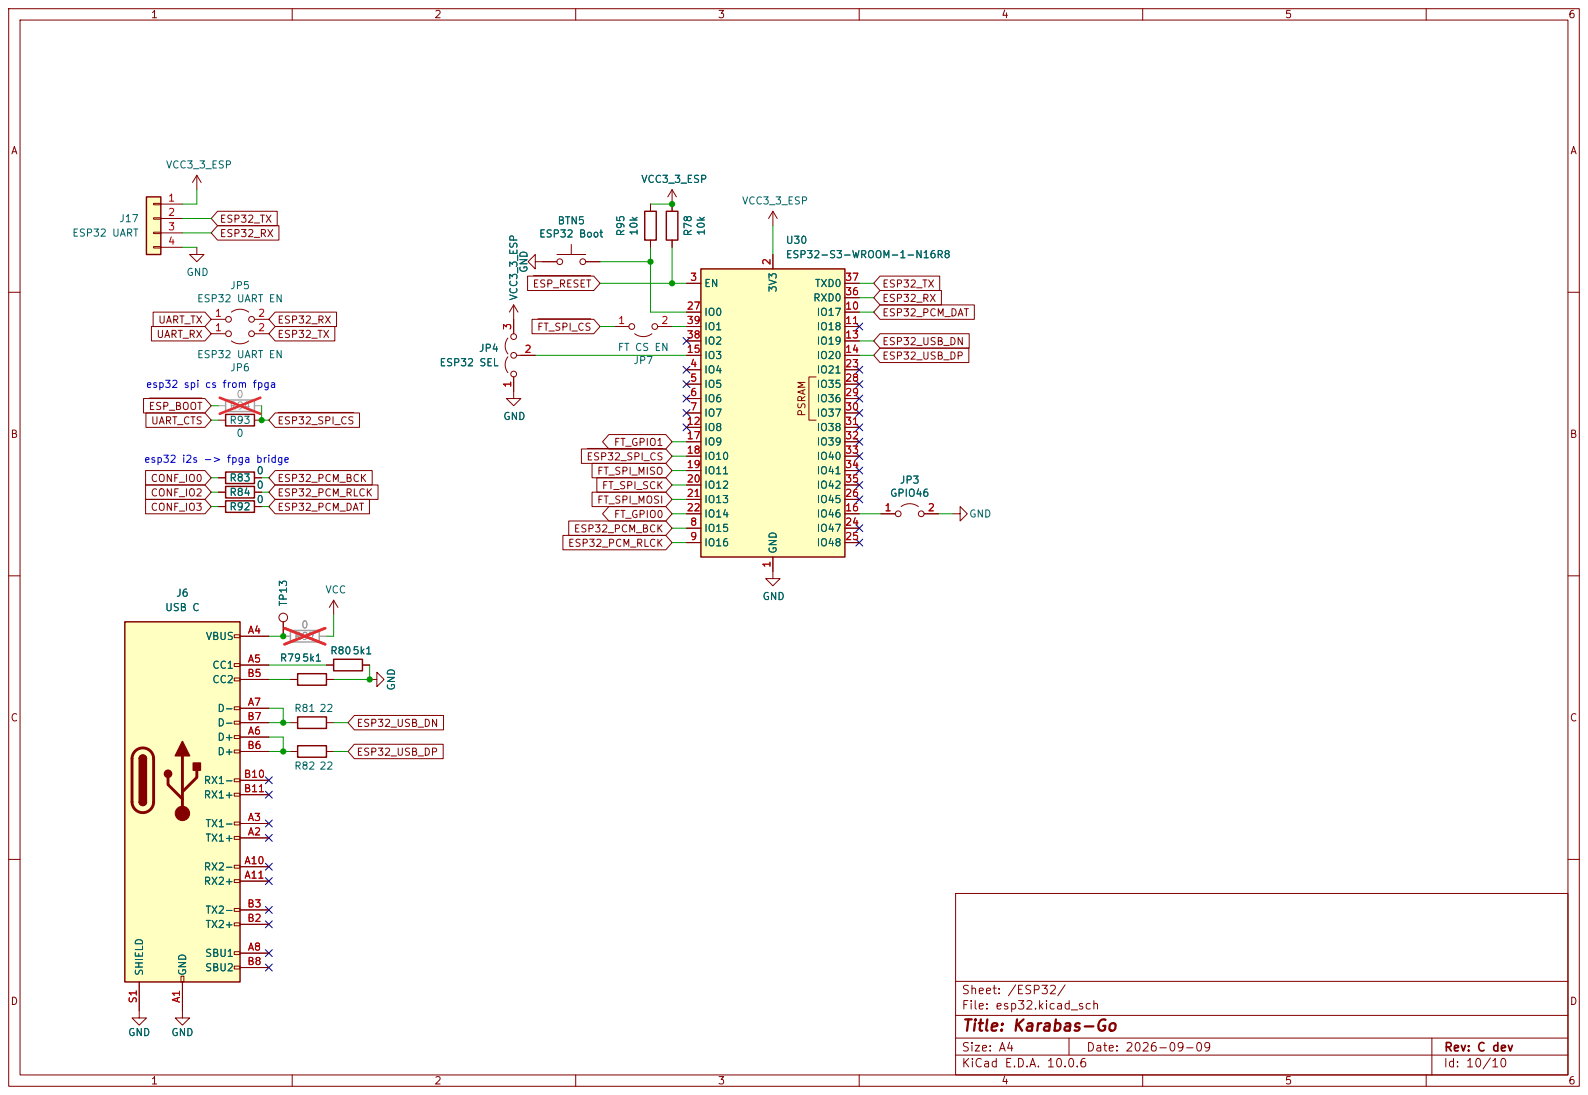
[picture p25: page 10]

esp32 spi cs from fpga

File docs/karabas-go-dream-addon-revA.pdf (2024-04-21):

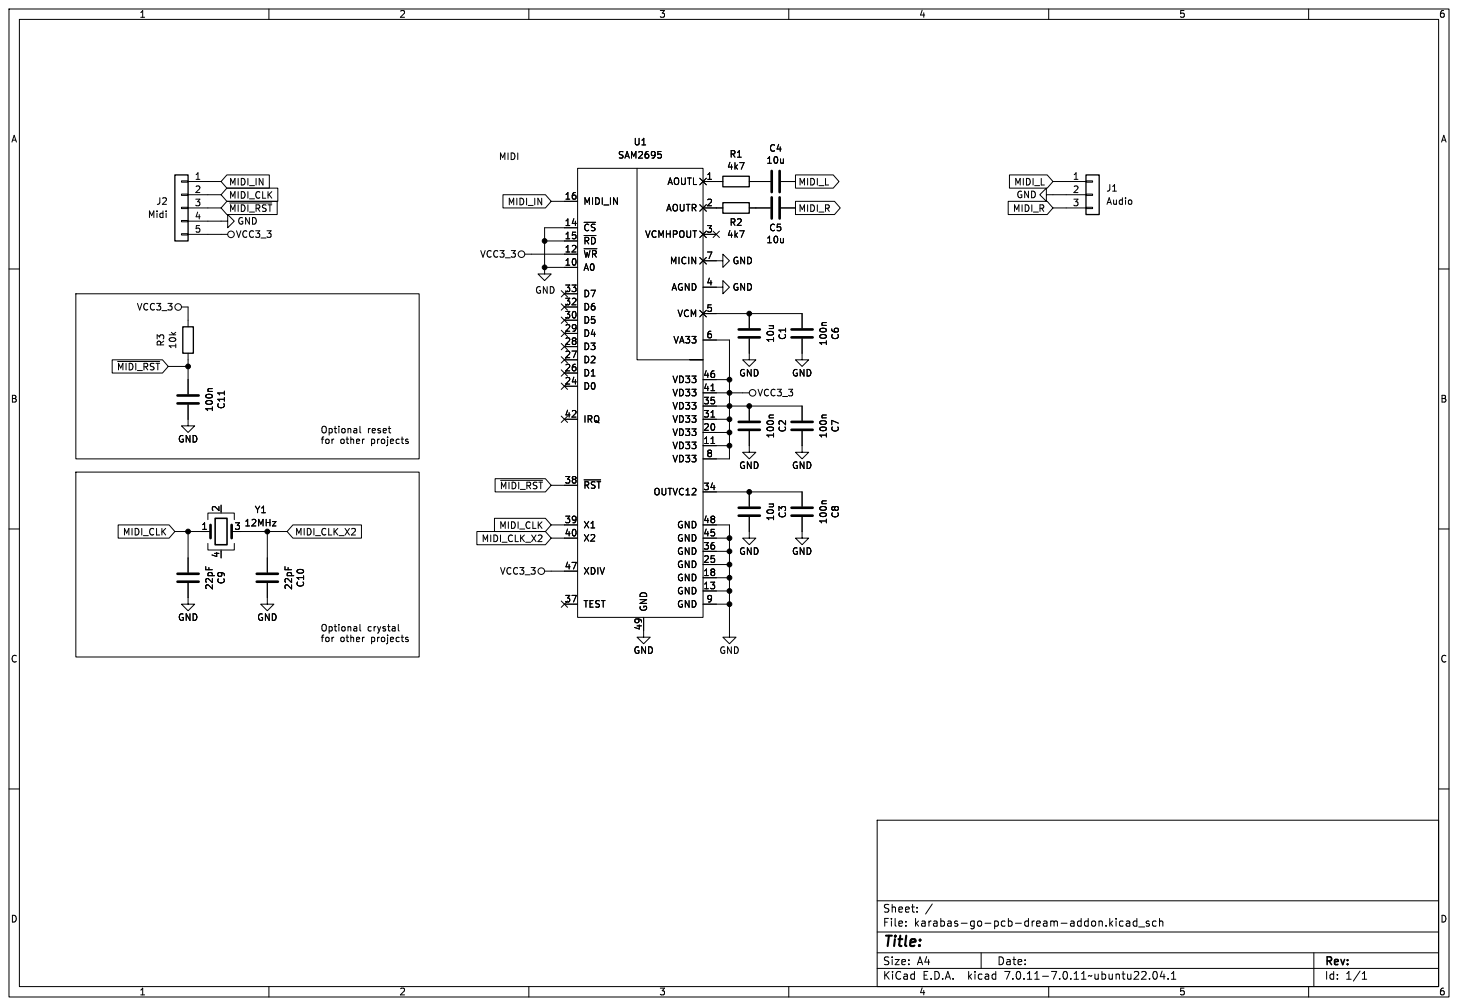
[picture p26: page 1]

Id: 1/1 Title: File: karabas-go-pcb-dream-addon.kicad_sch Sheet: /

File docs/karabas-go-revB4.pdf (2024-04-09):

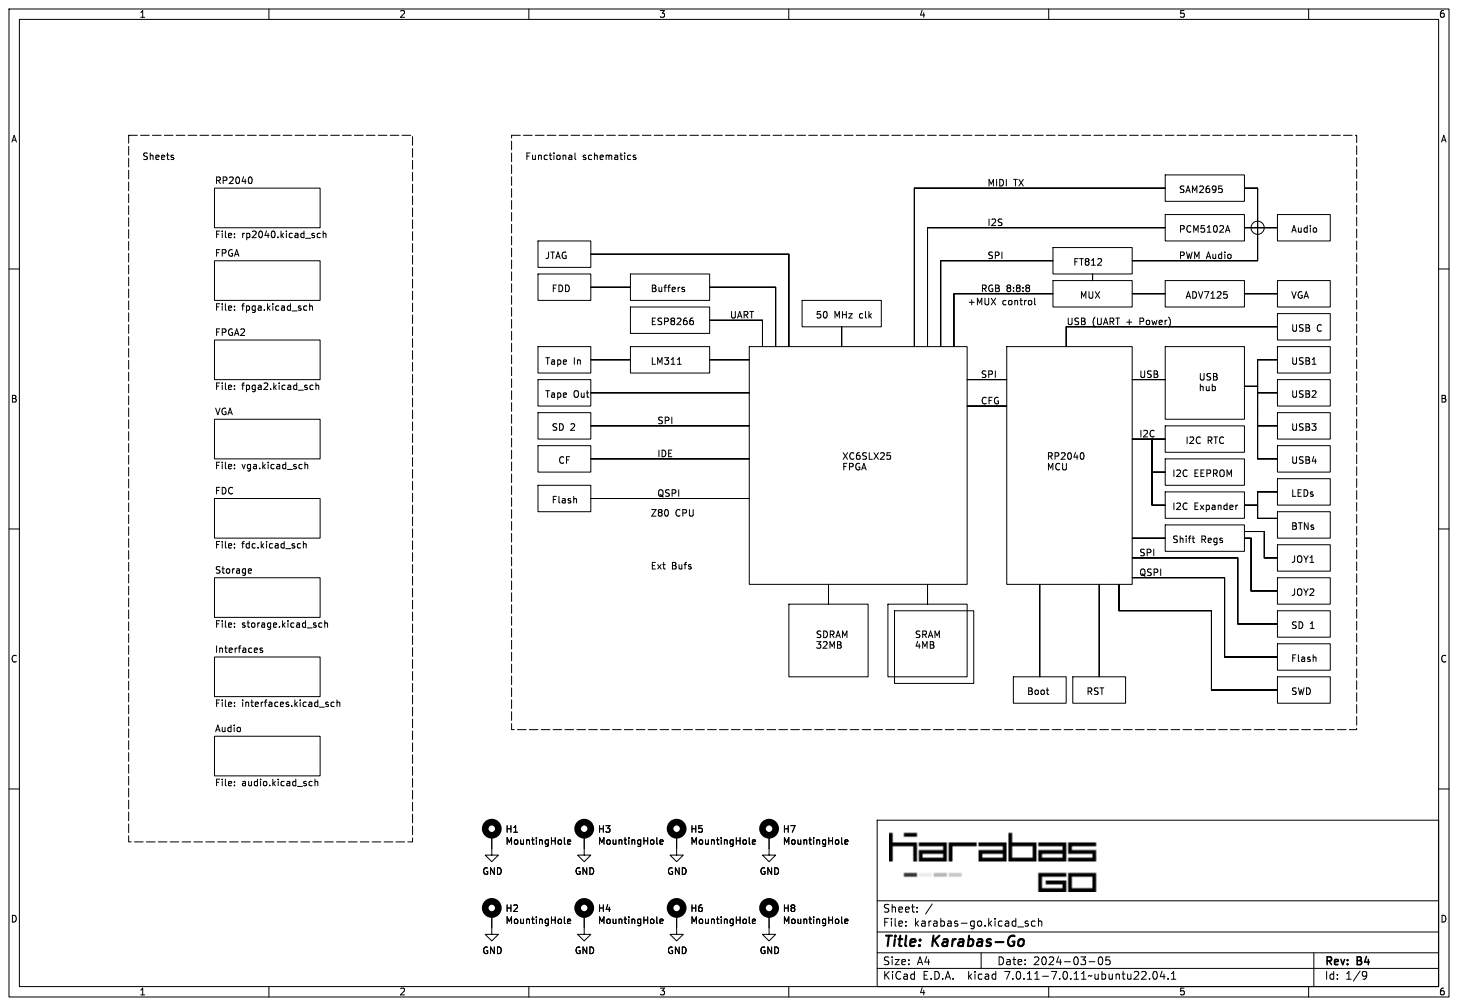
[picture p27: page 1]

File: fpga.kicad_sch RP2040 File: rp2040.kicad_sch Audio File: audio.kicad_sch

FPGA2 File: fpga2.kicad_sch FPGA
Interfaces File: interfaces.kicad_sch VGA

Storage File: storage.kicad_sch FDC

File: karabas-go.kicad_sch Sheet: /
Id: 1/9 Title: Karabas-Go


6 SDA 7 SCL 8 U10 DS3231MZ VCC3_3 GND GND GND

6 SDA 7 SCL 8 GND GND

LCHCLK 12 SSFT/~{PLD} 13 SDA 14 A

1 IOVDD 10 GPIO8 11 GPIO9 12 GPIO10 13 GPIO11 14 GPIO12 15 GPIO13 16 GPIO14 17 GPIO15 18 TESTEN 19 GPIO0 2 XIN 20 XOUT 21 IOVDD 22 DVDD 23 SWCLK 24 SWD 25 RUN 26 GPIO16 27 GPIO17 28 GPIO18 29 GPIO1 3 GPIO19 30 GPIO20 31 GPIO21 32 IOVDD 33 GPIO22 34 GPIO23 35 GPIO24 36 GPIO25 37 GPIO26_ADC0 38 GPIO27_ADC1 39 GPIO2 4 GPIO28_ADC2 40 GPIO29_ADC3 41 IOVDD 42 ADC_AVDD 43 VREG_IN 44 VREG_VOUT 45 USB_DM 46 USB_DP 47 USB_VDD 48 IOVDD 49 GPIO3 5 DVDD 50 QSPI_SD3 51 QSPI_SCLK 52 QSPI_SD0 53 QSPI_SD2 54 QSPI_SD1 55 QSPI_SS 56 GND 57 GPIO4 6 GPIO5 7 GPIO6 8 GPIO7 9 U4 RP2040

1 IOVDD 10 GPIO8 11 GPIO9 12 GPIO10 13 GPIO11 14 GPIO12 15 GPIO13 16 GPIO14 17 GPIO15 18 TESTEN 19 GPIO0 2 XIN 20 XOUT 21 IOVDD 22 DVDD 23 SWCLK 24 SWD 25 RUN 26 GPIO16 27 GPIO17 28 GPIO18 29 GPIO1 3 GPIO19 30 GPIO20 31 GPIO21 32 IOVDD 33 GPIO22 34 GPIO23 35 GPIO24 36 GPIO25 37 GPIO26_ADC0 38 GPIO27_ADC1 39 GPIO2 4 GPIO28_ADC2 40 GPIO29_ADC3 41 IOVDD 42 ADC_AVDD 43 VREG_IN 44 VREG_VOUT 45 USB_DM 46 USB_DP 47 USB_VDD 48 IOVDD 49 GPIO3 5 DVDD 50 QSPI_SD3 51 QSPI_SCLK 52 QSPI_SD0 53 QSPI_SD2 54 QSPI_SD1 55 QSPI_SS 56 GND 57 GPIO4 6 GPIO5 7 GPIO6 8 GPIO7 9 +3.3VP R4 10k GND
100n R2 1k GND

4 SDA 5 SCL 6 WP 7 VCC

1 DM1 10 DP1 11 VD18_O 12 VD33 13 REXT 14 DMU 15 DPU 16 ~{XRSTJ} 17 VBUSM 18 BUSJ 19 XOUT 2 VDD5 20 VD33_O 21 DRV 22

I2C BTNs, LEDs Conf Flash

Id: 2/9 Title: Karabas-Go


Id: 3/9 Title: Karabas-Go


8 U11 W25Q128JVS GND TP8 VCC3_3 GND GND GND C67 100n

In order to use - short jumper

Id: 4/9 Title: Karabas-Go


File: vga.kicad_sch Sheet: /VGA/
Id: 5/9 Title: Karabas-Go


File: fdc.kicad_sch Sheet: /FDC/
Id: 6/9 Title: Karabas-Go


1 DQ5 10 DQ6 11 DQ7 13 DQML 15 ~{WE} 16 ~{CAS} 17 ~{RAS} 18 ~{CS} 19 DQ0 2 BA0 20 BA1 21 A10 22 A0 23 A1 24 A2 25 A3 26 VSS 28 A4 29 VDDQ

3 A5 30 A6 31 A7 32 A8 33 A9 34 A11 35 A12 36 CKE 37 CLK 38 DQMH 39 DQ1 4 DQ8 42 DQ9 44 DQ10 45 DQ11 47 DQ12 48 DQ2 5 DQ13 50 DQ14 51 DQ15 53 VSSQ

470 GND
File: storage.kicad_sch Sheet: /Storage/ GND

VCC3_3 CD2 10 SH 11 SH 12 SH 13 SH 14 SH 15
~{CS}2 DI 3 VDD 4 SCLK 5 GND 6 DO 7 CD1 9 J11

~{CS}2 DI 3 VDD 4 SCLK 5 GND 6 DO 7 CD1 9 J9

Id: 7/9 Title: Karabas-Go


1 DEMP 10 FLT 11 SCK 12 BCK 13 DIN 14

3 CAPM 4 VNEG 5 OUTL 6 OUTR 7 AVDD

Id: 8/9 Title: Karabas-Go


U29 could be one of the following: - MC4558

File: audio.kicad_sch Sheet: /Audio/
Id: 9/9 Title: Karabas-Go

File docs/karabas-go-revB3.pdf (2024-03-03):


File: fpga.kicad_sch RP2040 File: rp2040.kicad_sch Audio File: audio.kicad_sch

FPGA2 File: fpga2.kicad_sch FPGA
Interfaces File: interfaces.kicad_sch VGA

Storage File: storage.kicad_sch FDC

File: karabas-go.kicad_sch Sheet: /
Id: 1/9 Title: Karabas-Go


1 ~{RST} 10 SFTCLK 11
LCHCLK 12 SSFT/~{PLD} 13 SDA 14 A

1 IOVDD 10 GPIO8 11 GPIO9 12 GPIO10 13 GPIO11 14 GPIO12 15 GPIO13 16 GPIO14 17 GPIO15 18 TESTEN 19 GPIO0 2 XIN 20 XOUT 21 IOVDD 22 DVDD 23 SWCLK 24 SWD 25 RUN 26 GPIO16 27 GPIO17 28 GPIO18 29 GPIO1 3 GPIO19 30 GPIO20 31 GPIO21 32 IOVDD 33 GPIO22 34 GPIO23 35 GPIO24 36 GPIO25 37 GPIO26_ADC0 38 GPIO27_ADC1 39 GPIO2 4 GPIO28_ADC2 40 GPIO29_ADC3 41 IOVDD 42 ADC_AVDD 43 VREG_IN 44 VREG_VOUT 45 USB_DM 46 USB_DP 47 USB_VDD 48 IOVDD 49 GPIO3 5 DVDD 50 QSPI_SD3 51 QSPI_SCLK 52 QSPI_SD0 53 QSPI_SD2 54 QSPI_SD1 55 QSPI_SS 56 GND 57 GPIO4 6 GPIO5 7 GPIO6 8 GPIO7 9 U4 RP2040 C9

1 IOVDD 10 GPIO8 11 GPIO9 12 GPIO10 13 GPIO11 14 GPIO12 15 GPIO13 16 GPIO14 17 GPIO15 18 TESTEN 19 GPIO0 2 XIN 20 XOUT 21 IOVDD 22 DVDD 23 SWCLK 24 SWD 25 RUN 26 GPIO16 27 GPIO17 28 GPIO18 29 GPIO1 3 GPIO19 30 GPIO20 31 GPIO21 32 IOVDD 33 GPIO22 34 GPIO23 35 GPIO24 36 GPIO25 37 GPIO26_ADC0 38 GPIO27_ADC1 39 GPIO2 4 GPIO28_ADC2 40 GPIO29_ADC3 41 IOVDD 42 ADC_AVDD 43 VREG_IN 44 VREG_VOUT 45 USB_DM 46 USB_DP 47 USB_VDD 48 IOVDD 49 GPIO3 5 DVDD 50 QSPI_SD3 51 QSPI_SCLK 52 QSPI_SD0 53 QSPI_SD2 54 QSPI_SD1 55 QSPI_SS 56 GND 57 GPIO4 6 GPIO5 7 GPIO6 8 GPIO7 9 C4
100n GND

4 SDA 5 SCL 6 WP 7 VCC

1 DM1 10 DP1 11 VD18_O 12 VD33 13 REXT 14 DMU 15 DPU 16 ~{XRSTJ} 17 VBUSM 18 BUSJ 19 XOUT 2 VDD5 20 VD33_O 21 DRV 22

Id: 2/9 Title: Karabas-Go


Id: 3/9 Title: Karabas-Go


In order to use - short jumper

File: fpga2.kicad_sch Sheet: /FPGA2/
Id: 4/9 Title: Karabas-Go


FT Audio filter & mixer FT MCU Reset

File: vga.kicad_sch Sheet: /VGA/ C89

Id: 5/9 Title: Karabas-Go


Id: 6/9 Title: Karabas-Go


1 DQ5 10 DQ6 11 DQ7 13 DQML 15 ~{WE} 16 ~{CAS} 17 ~{RAS} 18 ~{CS} 19 DQ0 2 BA0 20 BA1 21 A10 22 A0 23 A1 24 A2 25 A3 26 VSS 28 A4 29 VDDQ

3 A5 30 A6 31 A7 32 A8 33 A9 34 A11 35 A12 36 CKE 37 CLK 38 DQMH 39 DQ1 4 DQ8 42 DQ9 44 DQ10 45 DQ11 47 DQ12 48 DQ2 5 DQ13 50 DQ14 51 DQ15 53 VSSQ

GND
~{CS}2 DI 3 VDD 4 SCLK 5 GND 6 DO 7 CD1 9 J9

File: storage.kicad_sch Sheet: /Storage/ C80

~{CS}2 DI 3 VDD 4 SCLK 5 GND 6 DO 7 CD1 9 J11

Id: 7/9 Title: Karabas-Go


Audio DAC Beeper MIDI Interconnection

1 DEMP 10 FLT 11 SCK 12 BCK 13 DIN 14

3 CAPM 4 VNEG 5 OUTL 6 OUTR 7 AVDD

JP2 On/Off GND VCC3_3 GND R47 1M

8 CS0 9 GND R61 10k GND GND GND C41 100n GND GND GND

File: interfaces.kicad_sch Sheet: /Interfaces/
Id: 8/9 Title: Karabas-Go


Id: 9/9 Title: Karabas-Go

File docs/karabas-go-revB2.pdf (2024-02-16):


File: fpga.kicad_sch RP2040 File: rp2040.kicad_sch Audio File: audio.kicad_sch

FPGA2 File: fpga2.kicad_sch FPGA
Interfaces File: interfaces.kicad_sch VGA

Storage File: storage.kicad_sch FDC

File: karabas-go.kicad_sch Sheet: /
Id: 1/9 Title: Karabas-Go


1 IOVDD 10 GPIO8 11 GPIO9 12 GPIO10 13 GPIO11 14 GPIO12 15 GPIO13 16 GPIO14 17 GPIO15 18 TESTEN 19 GPIO0 2 XIN 20 XOUT 21 IOVDD 22 DVDD 23 SWCLK 24 SWD 25 RUN 26 GPIO16 27 GPIO17 28 GPIO18 29 GPIO1 3 GPIO19 30 GPIO20 31 GPIO21 32 IOVDD 33 GPIO22 34 GPIO23 35 GPIO24 36 GPIO25 37 GPIO26_ADC0 38 GPIO27_ADC1 39 GPIO2 4 GPIO28_ADC2 40 GPIO29_ADC3 41 IOVDD 42 ADC_AVDD 43 VREG_IN 44 VREG_VOUT 45 USB_DM 46 USB_DP 47 USB_VDD 48 IOVDD 49 GPIO3 5 DVDD 50 QSPI_SD3 51 QSPI_SCLK 52 QSPI_SD0 53 QSPI_SD2 54 QSPI_SD1 55 QSPI_SS 56 GND 57 GPIO4 6 GPIO5 7 GPIO6 8 GPIO7 9 U4 RP2040 VCC3_3 GND

1 IOVDD 10 GPIO8 11 GPIO9 12 GPIO10 13 GPIO11 14 GPIO12 15 GPIO13 16 GPIO14 17 GPIO15 18 TESTEN 19 GPIO0 2 XIN 20 XOUT 21 IOVDD 22 DVDD 23 SWCLK 24 SWD 25 RUN 26 GPIO16 27 GPIO17 28 GPIO18 29 GPIO1 3 GPIO19 30 GPIO20 31 GPIO21 32 IOVDD 33 GPIO22 34 GPIO23 35 GPIO24 36 GPIO25 37 GPIO26_ADC0 38 GPIO27_ADC1 39 GPIO2 4 GPIO28_ADC2 40 GPIO29_ADC3 41 IOVDD 42 ADC_AVDD 43 VREG_IN 44 VREG_VOUT 45 USB_DM 46 USB_DP 47 USB_VDD 48 IOVDD 49 GPIO3 5 DVDD 50 QSPI_SD3 51 QSPI_SCLK 52 QSPI_SD0 53 QSPI_SD2 54 QSPI_SD1 55 QSPI_SS 56 GND 57 GPIO4 6 GPIO5 7 GPIO6 8 GPIO7 9 GND

4 SDA 5 SCL 6 WP 7 VCC

1 ~{RST} 10 SFTCLK 11
LCHCLK 12 SSFT/~{PLD} 13 SDA 14 A

D1 Keyboard D2 Activitty BTN3 Magic BTN4 Reset C4

1 DM1 10 DP1 11 VD18_O 12 VD33 13 REXT 14 DMU 15 DPU 16 ~{XRSTJ} 17 VBUSM 18 BUSJ 19 XOUT 2 VDD5 20 VD33_O 21 DRV 22

File: rp2040.kicad_sch Sheet: /RP2040/
Id: 2/9 Title: Karabas-Go


Id: 3/9 Title: Karabas-Go


In order to use - short jumper

File: fpga2.kicad_sch Sheet: /FPGA2/
Id: 4/9 Title: Karabas-Go


Id: 5/9 Title: Karabas-Go


Id: 6/9 Title: Karabas-Go


1 DQ5 10 DQ6 11 DQ7 13 DQML 15 ~{WE} 16 ~{CAS} 17 ~{RAS} 18 ~{CS} 19 DQ0 2 BA0 20 BA1 21 A10 22 A0 23 A1 24 A2 25 A3 26 VSS 28 A4 29 VDDQ

3 A5 30 A6 31 A7 32 A8 33 A9 34 A11 35 A12 36 CKE 37 CLK 38 DQMH 39 DQ1 4 DQ8 42 DQ9 44 DQ10 45 DQ11 47 DQ12 48 DQ2 5 DQ13 50 DQ14 51 DQ15 53 VSSQ

100n GND
~{CS}2 DI 3 VDD 4 SCLK 5 GND 6 DO 7 CD1 9 J9

File: storage.kicad_sch Sheet: /Storage/ GND GND
~{CS}2 DI 3 VDD 4 SCLK 5 GND 6 DO 7 CD1 9 J11
uSD card

Id: 7/9 Title: Karabas-Go


1 DEMP 10 FLT 11 SCK 12 BCK 13 DIN 14

3 CAPM 4 VNEG 5 OUTL 6 OUTR 7 AVDD

8 CS0 9 U26 ESP-12E GND C44 GND 100n GND R66 1k R67 470 R65 10k C101

8 CS0 9 GND C44 100n GND R66 1k R67 470 R65 10k GND GND C40 100n GND GND

File: interfaces.kicad_sch Sheet: /Interfaces/ C97 100n

Id: 8/9 Title: Karabas-Go


File: audio.kicad_sch Sheet: /Audio/ R89 47k C109

Id: 9/9 Title: Karabas-Go

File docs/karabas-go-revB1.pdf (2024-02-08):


hub MUX USB (UART + Power) FT812 SPI CFG

FPGA
Interfaces File: interfaces.kicad_sch VGA

Storage File: storage.kicad_sch FDC

H7 MountingHole GND GND GND

File: karabas-go.kicad_sch Sheet: /
Id: 1/8 Title: Karabas-Go


6 SDA 7 SCL 8 GND GND

1 IOVDD 10 GPIO8 11 GPIO9 12 GPIO10 13 GPIO11 14 GPIO12 15 GPIO13 16 GPIO14 17 GPIO15 18 TESTEN 19 GPIO0 2 XIN 20 XOUT 21 IOVDD 22 DVDD 23 SWCLK 24 SWD 25 RUN 26 GPIO16 27 GPIO17 28 GPIO18 29 GPIO1 3 GPIO19 30 GPIO20 31 GPIO21 32 IOVDD 33 GPIO22 34 GPIO23 35 GPIO24 36 GPIO25 37 GPIO26_ADC0 38 GPIO27_ADC1 39 GPIO2 4 GPIO28_ADC2 40 GPIO29_ADC3 41 IOVDD 42 ADC_AVDD 43 VREG_IN 44 VREG_VOUT 45 USB_DM 46 USB_DP 47 USB_VDD 48 IOVDD 49 GPIO3 5 DVDD 50 QSPI_SD3 51 QSPI_SCLK 52 QSPI_SD0 53 QSPI_SD2 54 QSPI_SD1 55 QSPI_SS 56 GND 57 GPIO4 6 GPIO5 7 GPIO6 8 GPIO7 9 U4 RP2040 GND

1 IOVDD 10 GPIO8 11 GPIO9 12 GPIO10 13 GPIO11 14 GPIO12 15 GPIO13 16 GPIO14 17 GPIO15 18 TESTEN 19 GPIO0 2 XIN 20 XOUT 21 IOVDD 22 DVDD 23 SWCLK 24 SWD 25 RUN 26 GPIO16 27 GPIO17 28 GPIO18 29 GPIO1 3 GPIO19 30 GPIO20 31 GPIO21 32 IOVDD 33 GPIO22 34 GPIO23 35 GPIO24 36 GPIO25 37 GPIO26_ADC0 38 GPIO27_ADC1 39 GPIO2 4 GPIO28_ADC2 40 GPIO29_ADC3 41 IOVDD 42 ADC_AVDD 43 VREG_IN 44 VREG_VOUT 45 USB_DM 46 USB_DP 47 USB_VDD 48 IOVDD 49 GPIO3 5 DVDD 50 QSPI_SD3 51 QSPI_SCLK 52 QSPI_SD0 53 QSPI_SD2 54 QSPI_SD1 55 QSPI_SS 56 GND 57 GPIO4 6 GPIO5 7 GPIO6 8 GPIO7 9 Y1

4 SDA 5 SCL 6 WP 7 VCC

LCHCLK 12 SSFT/~{PLD} 13 SDA 14 A

1 DM1 10 DP1 11 VD18_O 12 VD33 13 REXT 14 DMU 15 DPU 16 ~{XRSTJ} 17 VBUSM 18 BUSJ 19 XOUT 2 VDD5 20 VD33_O 21 DRV 22

BTN4 Reset BTN3 Magic GND ~{CS} 1 DO(IO1) 2

Id: 2/8 Title: Karabas-Go


Id: 3/8 Title: Karabas-Go


In order to use - short jumper

Id: 4/8 Title: Karabas-Go


File: vga.kicad_sch Sheet: /VGA/
Id: 5/8 Title: Karabas-Go


File: fdc.kicad_sch Sheet: /FDC/
Id: 6/8 Title: Karabas-Go


2 ~{INT}/SQW3 ~{RST} 4 U10'1 DS3231M GND GND

1 DQ5 10 DQ6 11 DQ7 13 DQML 15 ~{WE} 16 ~{CAS} 17 ~{RAS} 18 ~{CS} 19 DQ0 2 BA0 20 BA1 21 A10 22 A0 23 A1 24 A2 25 A3 26 VSS 28 A4 29 VDDQ

3 A5 30 A6 31 A7 32 A8 33 A9 34 A11 35 A12 36 CKE 37 CLK 38 DQMH 39 DQ1 4 DQ8 42 DQ9 44 DQ10 45 DQ11 47 DQ12 48 DQ2 5 DQ13 50 DQ14 51 DQ15 53 VSSQ

File: storage.kicad_sch Sheet: /Storage/ GND GND
100n VCC3_3 R37

~{CS}2 DI 3 VDD 4 SCLK 5 GND 6 DO 7 CD1 9 J11

2 ~{INT}/SQW3 ~{RST} 4 GND GND

~{CS}2 DI 3 VDD 4 SCLK 5 GND 6 DO 7 CD1 9 J9

Id: 7/8 Title: Karabas-Go


9 C41 C39 100n 10u GND C38 2u2C45 2n2 C47 100n GND GND C43 10u GND

1 DEMP 10 FLT 11 SCK 12 BCK 13 DIN 14

3 CAPM 4 VNEG 5 OUTL 6 OUTR 7 AVDD

File: interfaces.kicad_sch Sheet: /Interfaces/
Id: 8/8 Title: Karabas-Go

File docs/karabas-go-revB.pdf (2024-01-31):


File: vga.kicad_sch RP2040 File: rp2040.kicad_sch FPGA

hub USB (UART + Power) USB

H7 MountingHole H8 MountingHole H5 MountingHole GND

File: karabas-go.kicad_sch Sheet: /
Id: 1/8 Title: Karabas-Go


LCHCLK 12 SSFT/~{PLD} 13 SDA 14 A

1 IOVDD 10 GPIO8 11 GPIO9 12 GPIO10 13 GPIO11 14 GPIO12 15 GPIO13 16 GPIO14 17 GPIO15 18 TESTEN 19 GPIO0 2 XIN 20 XOUT 21 IOVDD 22 DVDD 23 SWCLK 24 SWD 25 RUN 26 GPIO16 27 GPIO17 28 GPIO18 29 GPIO1 3 GPIO19 30 GPIO20 31 GPIO21 32 IOVDD 33 GPIO22 34 GPIO23 35 GPIO24 36 GPIO25 37 GPIO26_ADC0 38 GPIO27_ADC1 39 GPIO2 4 GPIO28_ADC2 40 GPIO29_ADC3 41 IOVDD 42 ADC_AVDD 43 VREG_IN 44 VREG_VOUT 45 USB_DM 46 USB_DP 47 USB_VDD 48 IOVDD 49 GPIO3 5 DVDD 50 QSPI_SD3 51 QSPI_SCLK 52 QSPI_SD0 53 QSPI_SD2 54 QSPI_SD1 55 QSPI_SS 56 GND 57 GPIO4 6 GPIO5 7 GPIO6 8 GPIO7 9 U4 RP2040 GND GND

1 IOVDD 10 GPIO8 11 GPIO9 12 GPIO10 13 GPIO11 14 GPIO12 15 GPIO13 16 GPIO14 17 GPIO15 18 TESTEN 19 GPIO0 2 XIN 20 XOUT 21 IOVDD 22 DVDD 23 SWCLK 24 SWD 25 RUN 26 GPIO16 27 GPIO17 28 GPIO18 29 GPIO1 3 GPIO19 30 GPIO20 31 GPIO21 32 IOVDD 33 GPIO22 34 GPIO23 35 GPIO24 36 GPIO25 37 GPIO26_ADC0 38 GPIO27_ADC1 39 GPIO2 4 GPIO28_ADC2 40 GPIO29_ADC3 41 IOVDD 42 ADC_AVDD 43 VREG_IN 44 VREG_VOUT 45 USB_DM 46 USB_DP 47 USB_VDD 48 IOVDD 49 GPIO3 5 DVDD 50 QSPI_SD3 51 QSPI_SCLK 52 QSPI_SD0 53 QSPI_SD2 54 QSPI_SD1 55 QSPI_SS 56 GND 57 GPIO4 6 GPIO5 7 GPIO6 8 GPIO7 9 GND

4 SDA 5 SCL 6 WP 7 VCC

9 VCC3_3 C65
1 ~{RST} 10 SFTCLK 11

1 DM1 10 DP1 11 VD18_O 12 VD33 13 REXT 14 DMU 15 DPU 16 ~{XRSTJ} 17 VBUSM 18 BUSJ 19 XOUT 2 VDD5 20 VD33_O 21 DRV 22

BTN1 RP Boot BTN2 RP Reset GND

File: rp2040.kicad_sch Sheet: /RP2040/
Id: 2/8 Title: Karabas-Go


Id: 3/8 Title: Karabas-Go


In order to use - short jumper GND

File: fpga2.kicad_sch Sheet: /FPGA2/
Id: 4/8 Title: Karabas-Go


File: vga.kicad_sch Sheet: /VGA/
Id: 5/8 Title: Karabas-Go


Id: 6/8 Title: Karabas-Go


6 DQ3 7 DQ4 8 U20 IS61WV20488BLL-10TLI NC 1 D1 10 VCC 11 GND 12 D2 13 D3 14 ~{WE} 15 A5 16 A6 17 A7 18 A8 19 NC 2 A9 20 NC 21 NC 22 NC 23 NC 24 A19 25 A10 26 A11 27 A12 28 A13 29 A0 3 A14 30 D4 31 D5 32 VCC 33 GND 34 D6 35 D7 36 ~{OE} 37 A15 38 A16 39 A1 4 A17 40 A18 41 A20 42 NC 43 NC 44 A2 5 A3 6 A4 7 ~{CE} 8 D0 9 GND

1 DQ5 10 DQ6 11 DQ7 13 DQML 15 ~{WE} 16 ~{CAS} 17 ~{RAS} 18 ~{CS} 19 DQ0 2 BA0 20 BA1 21 A10 22 A0 23 A1 24 A2 25 A3 26 VSS 28 A4 29 VDDQ

3 A5 30 A6 31 A7 32 A8 33 A9 34 A11 35 A12 36 CKE 37 CLK 38 DQMH 39 DQ1 4 DQ8 42 DQ9 44 DQ10 45 DQ11 47 DQ12 48 DQ2 5 DQ13 50 DQ14 51 DQ15 53 VSSQ

~{CS}2 DI 3 VDD 4 SCLK 5 GND 6 DO 7 CD1 9 J11

~{CS}2 DI 3 VDD 4 SCLK 5 GND 6 DO 7 CD1 9 J9

File: storage.kicad_sch Sheet: /Storage/
Id: 7/8 Title: Karabas-Go


J16 Sound Out 1 2 JP2 On/Off 1

1 DEMP 10 FLT 11 SCK 12 BCK 13 DIN 14

3 CAPM 4 VNEG 5 OUTL 6 OUTR 7 AVDD

8 CS0 9 U26 ESP-12E GND R66 1k GND C44 GND 100n GND C40 100n GND

8 CS0 9 GND R66 1k GND C44 100n GND C40 100n GND

1 VO 2 VI 3 VCC GND

File: interfaces.kicad_sch Sheet: /Interfaces/ GND

Id: 8/8 Title: Karabas-Go

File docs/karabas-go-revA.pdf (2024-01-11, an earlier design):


File: vga.kicad_sch RP2040 File: rp2040.kicad_sch FPGA

hub USB (UART + Power) USB

H7 MountingHole H8 MountingHole H5 MountingHole GND

File: karabas-go.kicad_sch Sheet: /
Id: 1/8 Title: Karabas-Go


1 IOVDD 10 GPIO8 11 GPIO9 12 GPIO10 13 GPIO11 14 GPIO12 15 GPIO13 16 GPIO14 17 GPIO15 18 TESTEN 19 GPIO0 2 XIN 20 XOUT 21 IOVDD 22 DVDD 23 SWCLK 24 SWD 25 RUN 26 GPIO16 27 GPIO17 28 GPIO18 29 GPIO1 3 GPIO19 30 GPIO20 31 GPIO21 32 IOVDD 33 GPIO22 34 GPIO23 35 GPIO24 36 GPIO25 37 GPIO26_ADC0 38 GPIO27_ADC1 39 GPIO2 4 GPIO28_ADC2 40 GPIO29_ADC3 41 IOVDD 42 ADC_AVDD 43 VREG_IN 44 VREG_VOUT 45 USB_DM 46 USB_DP 47 USB_VDD 48 IOVDD 49 GPIO3 5 DVDD 50 QSPI_SD3 51 QSPI_SCLK 52 QSPI_SD0 53 QSPI_SD2 54 QSPI_SD1 55 QSPI_SS 56 GND 57 GPIO4 6 GPIO5 7 GPIO6 8 GPIO7 9 U4 RP2040 R3

1 IOVDD 10 GPIO8 11 GPIO9 12 GPIO10 13 GPIO11 14 GPIO12 15 GPIO13 16 GPIO14 17 GPIO15 18 TESTEN 19 GPIO0 2 XIN 20 XOUT 21 IOVDD 22 DVDD 23 SWCLK 24 SWD 25 RUN 26 GPIO16 27 GPIO17 28 GPIO18 29 GPIO1 3 GPIO19 30 GPIO20 31 GPIO21 32 IOVDD 33 GPIO22 34 GPIO23 35 GPIO24 36 GPIO25 37 GPIO26_ADC0 38 GPIO27_ADC1 39 GPIO2 4 GPIO28_ADC2 40 GPIO29_ADC3 41 IOVDD 42 ADC_AVDD 43 VREG_IN 44 VREG_VOUT 45 USB_DM 46 USB_DP 47 USB_VDD 48 IOVDD 49 GPIO3 5 DVDD 50 QSPI_SD3 51 QSPI_SCLK 52 QSPI_SD0 53 QSPI_SD2 54 QSPI_SD1 55 QSPI_SS 56 GND 57 GPIO4 6 GPIO5 7 GPIO6 8 GPIO7 9 C3

4 SDA 5 SCL 6 WP 7 VCC GND 8 C63
24LC08B GND

4 SDA 5 SCL 6 WP 7 VCC

LCHCLK 12 SSFT/~{PLD} 13 SDA 14 A

1 DM1 10 DP1 11 VD18_O 12 VD33 13 REXT 14 DMU 15 DPU 16 ~{XRSTJ} 17 VBUSM 18 BUSJ 19 XOUT 2 VDD5 20 VD33_O 21 DRV 22

Id: 2/8 Title: Karabas-Go


Id: 3/8 Title: Karabas-Go


In order to use - short jumper GND

File: fpga2.kicad_sch Sheet: /FPGA2/
Id: 4/8 Title: Karabas-Go


File: vga.kicad_sch Sheet: /VGA/
Id: 5/8 Title: Karabas-Go


Id: 6/8 Title: Karabas-Go


1 DQ5 10 DQ6 11 DQ7 13 DQML 15 ~{WE} 16 ~{CAS} 17 ~{RAS} 18 ~{CS} 19 DQ0 2 BA0 20 BA1 21 A10 22 A0 23 A1 24 A2 25 A3 26 VSS 28 A4 29 VDDQ

3 A5 30 A6 31 A7 32 A8 33 A9 34 A11 35 A12 36 CKE 37 CLK 38 DQMH 39 DQ1 4 DQ8 42 DQ9 44 DQ10 45 DQ11 47 DQ12 48 DQ2 5 DQ13 50 DQ14 51 DQ15 53 VSSQ

~{CS}2 DI 3 VDD 4 SCLK 5 GND 6 DO 7 CD1 9 J11
uSD card

~{CS}2 DI 3 VDD 4 SCLK 5 GND 6 DO 7 CD1 9 J9

2 3 Q1 BC856 VCC3_3 CD2 10 SH 11 SH 12 SH 13 SH 14 SH 15

File: storage.kicad_sch Sheet: /Storage/
Id: 7/8 Title: Karabas-Go


J16 Sound Out 1 2 JP2 On/Off 1

1 DEMP 10 FLT 11 SCK 12 BCK 13 DIN 14

3 CAPM 4 VNEG 5 OUTL 6 OUTR 7 AVDD

8 CS0 9 U26 ESP-12E GND R66 1k GND C44 GND 100n GND C40 100n GND

8 CS0 9 GND R66 1k GND C44 100n GND C40 100n GND

1 VO 2 VI 3 VCC GND

File: interfaces.kicad_sch Sheet: /Interfaces/ GND

Id: 8/8 Title: Karabas-Go

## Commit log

2024-01-20 Fixed zifi uart
2024-01-26 Fixed mouse wheel
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2024-02-05 Added STL files for the test case without floppy
    [karabas-go-case-bot.stl, karabas-go-case-top.stl]
2024-02-08 Updated revB gerbers: changed buzzer footprint
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2024-02-15 Updated revB2: added FT_PD reset circuit + routed signal to the MCU TP9
2024-03-02 Added 3d models by xdemox
    [Karabas_Go_wd_case_bottom_v1.2.stl, Karabas_Go_wd_case_top_v1.0.stl, Karabas_Go_wd_logo_-_case_top_v1.0.stl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]
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2024-03-14 Fixed pcb changelog
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2024-04-01 Updated NES core: swapped A/B buttons
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2024-04-08 Fixed UART / zifi
2024-04-08 Updated firmware: fixed RTC 0x0b r/w, reduced MCU SPI speed
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2024-08-07 Rev.B4 case from sserg
    [Karabas_Go_wd_logo_-_case_top_v1.0. 20mm.stl]
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2026-05-31 Added slim case for revB4 with embedded gotek by Pavel Tsybulin
    [bottom.stl, front.stl, gotek-button-x2.stl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]
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2026-10-20 Boot menu build 26102001: kg_* modules, ESP uart and FT812 HDMI fixes
2026-10-23 Spec256 build 26102321: SDR_CLK phase fix (background artefacts on some boards)
2026-10-25 Firmware build 26102517: USB printer host (Epson LX-300) and XInput gamepads (8BitDo M30)
2026-10-25 Firmware build 26102519: USB joysticks: shared stable ports, drivers on the heap, fixes
2026-10-25 Firmware build 26102520: Driver ini v2: hat, axis ranges, inverted bits, several sources, report id
2026-10-25 Firmware build 26102523_113: Graphic setup: Esc asks before dropping changes, S button, G key, sound speed
2026-10-26 Firmware build 26102617: On-board buttons by the actions of the core (core.json buttons); MSC screen, no buttons at boot
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2026-10-26 Boot menu build 26102619: LED matrix shows the board name once, then the clock
2026-10-26 Firmware build 26102620: USB host: 3 hubs, 8 devices, 16 HID interfaces, 1024-byte enumeration buffer
2026-10-26 Firmware build 26102623: MSC eject: reboot when the host lets the device go, or 5 s after; SD2 transfers retried
2026-10-26 Firmware build 26102700: Serial bridge: flush the USB CDC every tick (ESP / core UART replies came late)
2026-10-27 Firmware build 26102701: LED matrix: the look of the clock and the audio meters in karabas.ini, Matrix effects page
2026-10-27 Firmware build 26102703: USB diagnostics: root port events, SOF timing, pin state, TinyUSB errors in the log
2026-10-27 Firmware build 26102713: USB host: upstream Pico-PIO-USB 0.7.3, the whole usb host on pio1
2026-10-28 Firmware build 26102802: Firmware in C11 on the pico-sdk: CMake, FreeRTOS, TinyUSB directly, the UI refactoring
2026-10-28 Firmware build 26102811: XInput: wake third-party Xbox 360 wired pads (no input since the pico-sdk move)
2026-10-28 Firmware build 26102813_300: Audit leftovers: less static RAM, printer on usb_host_lock, CMD_MATRIX_BITPLAN
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2026-10-28 Firmware build 26102816: Text OSD: full width Setup screens, centered buttons, core menu style choices
2026-10-30 Firmware build 26103022: Karabas Go: PCA9536 found by a register read, buttons as outputs high, read errors logged
2026-10-30 Firmware build 26103023: OSD file lists: filter by the item's extensions, show them, dirs with '/' in cyan
2026-10-30 Spec256 build 26103101: video 720x576 at 50 Hz, games at Spectrum speed
2026-10-31 PC XT build 26103107: OSD, HDD and floppy images, Sergey XT BIOS, DMA / 8288 / CPU microcode fixes
2026-10-31 Firmware build 26103114: USB MIDI keyboards: host class driver, CMD_MIDI 0x16 to cores with caps bit 4
2026-10-31 PC XT build 26103112: HDMI frame buffer in SDRAM (Mini / Mini G), Sergey BIOS 1.0.2, XTIDE r638
2026-10-31 PC/XT core 26103113: two joysticks, COM2 over USB, LPT1 on the USB printer
2026-10-31 Firmware build 26103118: USB-UART adapters on the USB host take the core UART
2026-10-31 PC/XT core 26103116: Sergey XT BIOS 1.0.2 with AdLib detection and the OPL power-on melody
2026-11-01 PC/XT core 26110101 (Go): VGA from the frame buffer (fixed 720x480 raster) for monitors that refused the scandoubled CGA
2026-11-01 Firmware build 26110118: CMD_FDD_CHNG 49: DSKCHG of the Go floppy through a hotfix wire on GPIO28
2026-11-01 NanoMig 26110101 (Go): real DSKCHG of the physical floppy with the board hotfix (Hotfix-DSKCHG.md of karabas-go-pcb), needs firmware v26110118 or later for it
2026-11-02 NanoMig 26110106 (Go): the physical floppy reads and formats without errors
    The floppy fifo gave a stale word when the only word was read in the cycle
    the PLL wrote the next one: the read errors and the failed Format on
    cylinder 0 of a real drive. Also 8 us DIR setup and STEP pulses (lost steps
    on a real drive with 2.8 / 1 us). Tested on hardware: reads, disk change
    and Format work. Core: karabas-go-core-nanomig PR #14.
2026-11-02 BaseConf 26110107: ERS 0.61 without DOS_FE again, TRD images mount in the ERS
2026-11-02 BaseConf 26110201: TR-DOS emulation of base_trdemu, ERS 0.61.01 FE (TRD mount through dos_fe)
2026-11-04 Firmware build 26110414: Read kgo2 core files (.kg): one file for several boards
2026-11-04 Cores as kgo2 files (.kg): one file for Go, Mini and Mini G
    Every core of cores/ is now one .kg file with the bitstreams of all the boards
    (karabas-go-tools docs/kgo2.md), packed from the core repos (their kgo2 PRs)
    without a new build; pong.kg is converted from the old pong.kg1 (no sources).
    karabas-go-tools kg_compare.py: each board gets what the old .kg1 / .kg2 /
    .kg3 gave, except next186 on Mini / Mini G, which now has the BIOS of the Go
    build 26110101 (the one in the core repo). The settings of a .kg core are kept
    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
2026-11-04 CLAUDE.md, howto: the cores of all the boards are here (karabas-mini has none)
2026-11-04 One repo for the family: Karabas Go, Mini and Mini G
    karabas-mini is merged in (its files copied, without their history; the repo
    gets archived and points here):
    - firmware/: karabas_go.uf2 (was firmware.uf2), karabas_mini.uf2,
    karabas_minig.uf2 (were firmware.uf2 / firmware_g.uf2 of karabas-mini),
    esp32-s3/ and esp32-s3-old-zifi/ of the Mini G shield;
    - pcb/go, case/go, docs/go: the Go files moved (git mv), pcb/go/PCB_CHANGELOG.md;
    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
2026-11-06 Orion-128 build 26110601: Phase 5: Go and Mini boards, tape, release 26110601 (karabas-go-core-orion128@775fcfe)
2026-11-06 Orion-128 build 26110604: Phase 6: joystick, physical floppy on the Go, 720 x 576 at 50 Hz (karabas-go-core-orion128@6688ea5)
2026-11-06 Orion-128 build 26110605: Monitor autoload, two Monitors in 4 KB, the UART of the Orion-2010 (karabas-go-core-orion128@acd0317)
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2026-11-08 Atari ST build 26110809: Mono through a frame buffer in the 576p output; MIDI IN from the firmware, MIDI OUT to the SAM2695; build 26110809 (karabas-go-core-atarist@1a8be65)
2026-11-08 Firmware build 26110819: Radio switches in the core menu, a hotkey per option
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2026-11-11 Commodore VIC-20 build 26111110: Ф6: cartridges of several files, Mega-Cart NVRAM in a file, the PRG reset fixed, build 26111110 (karabas-go-core-vic20@8d61d72)
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2026-11-14 Acorn Archimedes build 26111326: OSD: Reset the last item (its switch number pinned: "index": 1); archie.kg repacked, no synthesis (#10) (karabas-go-core-archie@f5a11b6)
2026-11-14 Alf build 26111345: OSD: Reset the last item (the switch numbers pinned by "index": Reset 0, Model 1, AY 2); alf.kg repacked, no synthesis (#14) (karabas-go-core-alf@08b8511)
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

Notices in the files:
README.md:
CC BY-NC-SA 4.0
